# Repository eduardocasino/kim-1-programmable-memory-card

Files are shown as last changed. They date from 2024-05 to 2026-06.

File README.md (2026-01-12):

# KIM-1 Programmable Memory Board for the MTU Backplane

## **WARNINGS**

**THIS IS A WORK IN PROGRESS AND MAY CONTAIN ERRORS. USE AT YOUR OWN RISK!!!**

**Make sure to configure composite video output when connecting a composite monitor, and VGA output when using a VGA monitor. The video data and HSYNC pins are shared between both connectors, and if not properly configured, the signal MAY DAMAGE your monitor — especially older models.**

## About

This is a fully programmable RAM/ROM expansion board for the KIM-1. Two hardware versions are available which use exactly the same firmware and tools:

* One for MTU backplanes, like the one in the original K-1005 card file, my [expansion card](https://github.com/eduardocasino/kim-1-mtu-expansion-card) or my [buffered motherboard](https://github.com/eduardocasino/kim-1-mtu-motherboard).
* One for the [PAL-2](https://www.tindie.com/products/kim1/pal-2-a-mos-6502-powered-computer-kit/), a KIM-1 clone by Liu GN. **IMPORTANT: Read the hardware specific notes for the PAL-2**.

There is also [an adapter](https://github.com/eduardocasino/kim-1-programmable-memory-card/tree/main/hardware/pal-2-kim-adapter) for connecting the PAL-2 version directly to the KIM-1 expansion connector. This is the best option if you don't have/need/want an MTU backplane.

It uses a Raspberry Pi Pico W to emulate the 64K RAM/ROM memory map, and has some cool features:

* Can emulate RAM and/or ROM at any address of the KIM-1 memory map and with byte granularity so you can individually enable, disable, mark as RW or RO each and every byte of the 64K address space. It can also take over the KIM-1 system RAM and ROM, so it can be used as a diagnostic tool or to relive a KIM-1 with dead RAM.
* A default memory map and data are stored in the Pico flash memory and it is available at boot time.
* Runs a configuration web server with a RESTish API so you can configure and read or write all or any part of memory contents over Wifi and on the fly.
* The board is powered by the KIM-1, but it can also be dual powered by the KIM-1 and the USB port. This is useful, for example, if you are developing a boot ROM: you can power off the KIM, modify the boot program over wifi and turn it on again to test your changes.
* It emulates an [MTU K-1008 Visable Memory Card](https://github.com/eduardocasino/k-1008-visable-memory-card-replica). It can be mapped to the same addresses as the real one (and change that mapping while running) and gives configurable composite NTSC or PAL output through the RCA connector or VGA output through the DB-15 one. Simultaneous composite and VGA output is not possible.
* Emulates an [K-1013 floppy disk controller](http://retro.hansotten.nl/uploads/mtu/MTU%20K-1013%20manual.pdf) with up to four disks, reading and writing to disk images into the SD card (Still in beta)

A config utility, memcfg, is provided to setup the board and facilitate the communication with the REST API. This is an overview of its functionality. Please see the [README.md file](https://github.com/eduardocasino/kim-1-programmable-memory-card/tree/main/tools) for detailed usage instructions:

* Generate configuration files ready to be flashed into the Pico: WiFi parameters, video format and default memory map and contents.
* Get or modify the memory map.
* Read memory contents and generate output in different formats: hexdump, Intel hex, binary, prg and raw. The raw format is how the Pico stores the memory map. Each memory address contains a 16 bit integer. The least significant byte is the content and the most significant one is a bitmap that indicates if the memory is enabled or disabled and writeable or read-only.
* Write memory contents from file or command line. The file formats supported are Intel hex, binary, prg and raw. Also, binary and raw data can be specified as a string from the command line.
* Modify the base address for the K-1008 emulation
* Manages disk images

### [KIM-1 version](https://github.com/eduardocasino/kim-1-programmable-memory-card/tree/main/hardware/kim-1-mtu)
### [PAL-2 version](https://github.com/eduardocasino/kim-1-programmable-memory-card/tree/main/hardware/pal-2)
### [KIM-1 adapter for the PAL-2 version](https://github.com/eduardocasino/kim-1-programmable-memory-card/tree/main/hardware/pal-2-kim-adapter)
### [Firmware](https://github.com/eduardocasino/kim-1-programmable-memory-card/tree/main/firmware)
### [Tools (memcfg)](https://github.com/eduardocasino/kim-1-programmable-memory-card/tree/main/tools)

***NOTE***: This is a picture of a KIM-1 version prototype. The bodges are not needed in the current design.

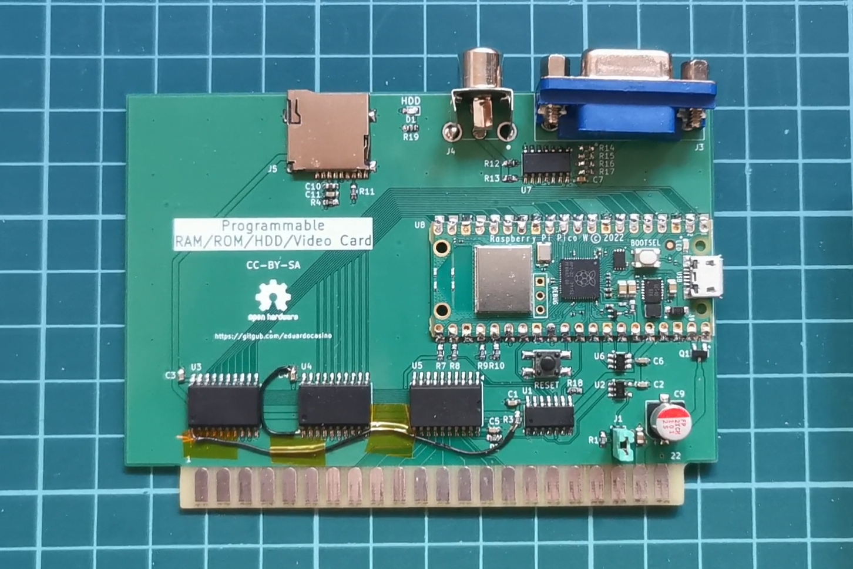
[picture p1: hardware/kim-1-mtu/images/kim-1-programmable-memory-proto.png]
kim-1 prototype


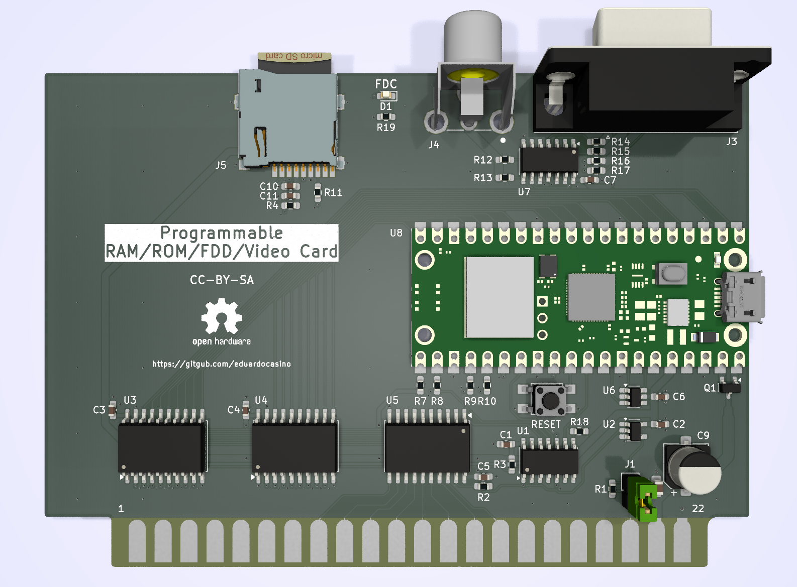
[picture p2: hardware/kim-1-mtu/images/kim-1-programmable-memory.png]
kim-1 components

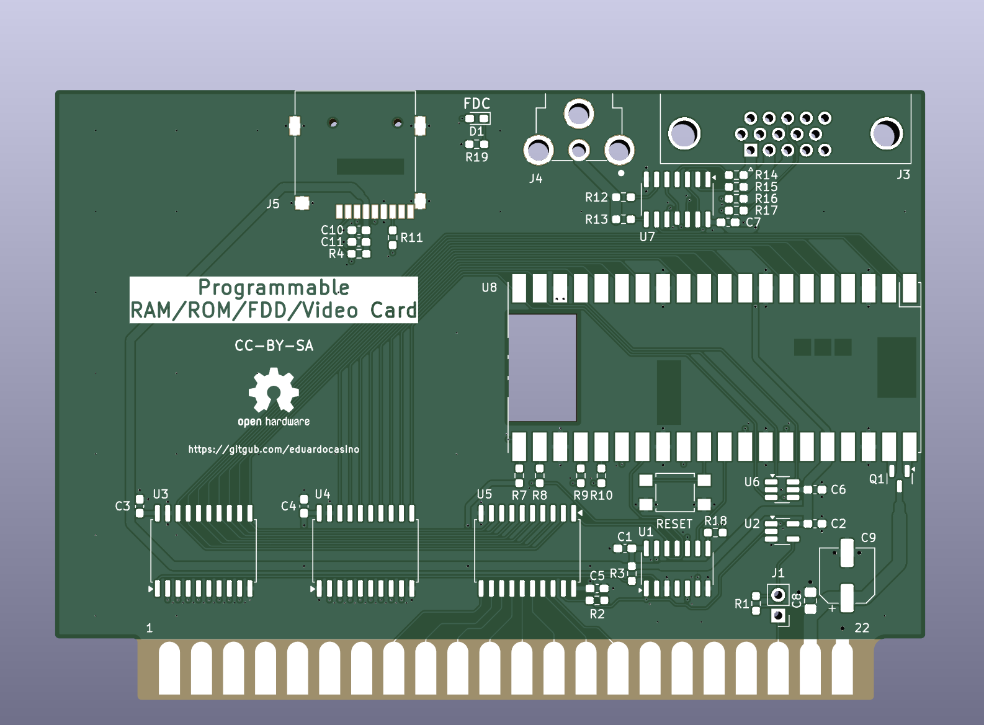
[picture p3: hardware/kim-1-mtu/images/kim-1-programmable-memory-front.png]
kim-1 front

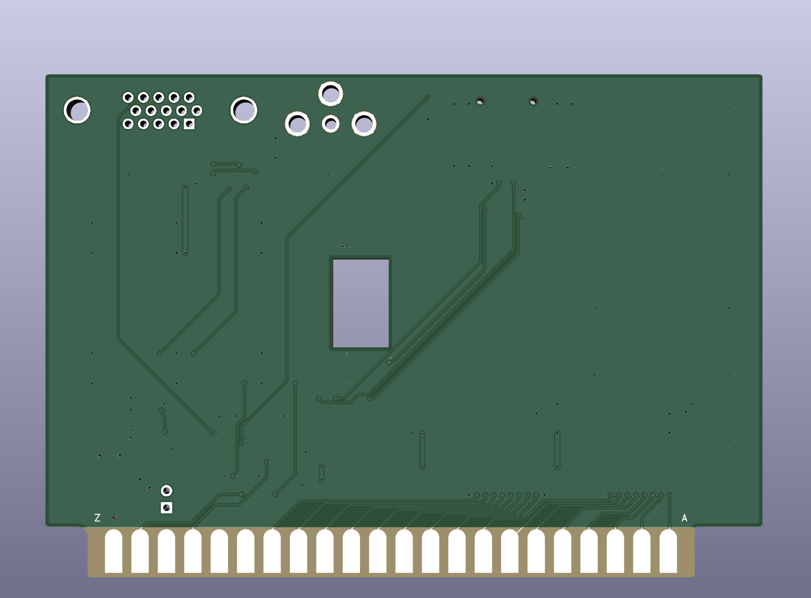
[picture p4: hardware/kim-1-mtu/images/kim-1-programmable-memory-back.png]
kim-1 back


pal-2 components
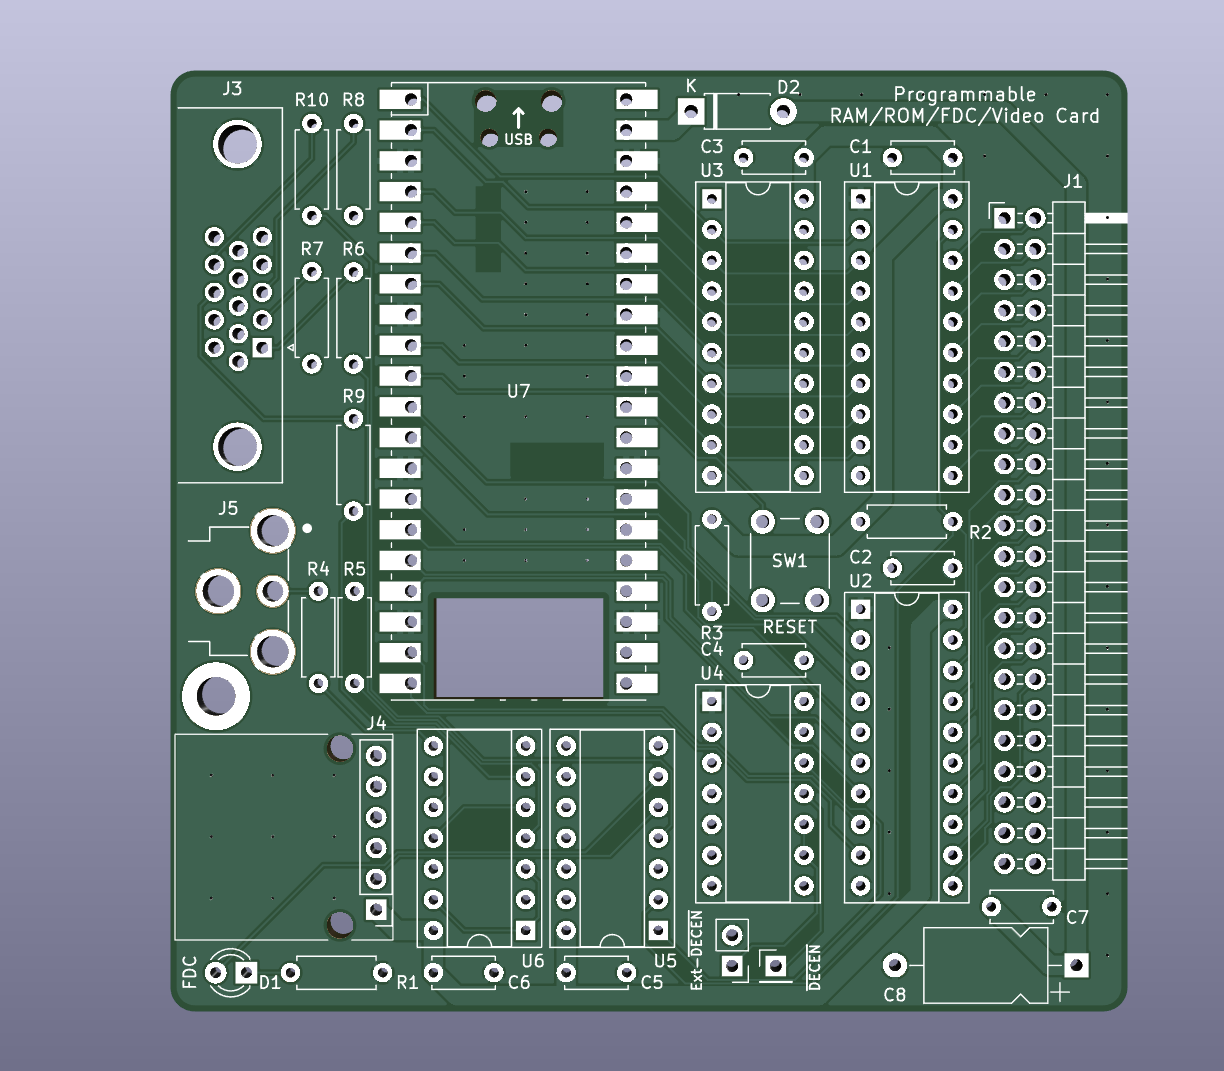
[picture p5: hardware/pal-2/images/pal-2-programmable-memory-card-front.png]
pal-2 front

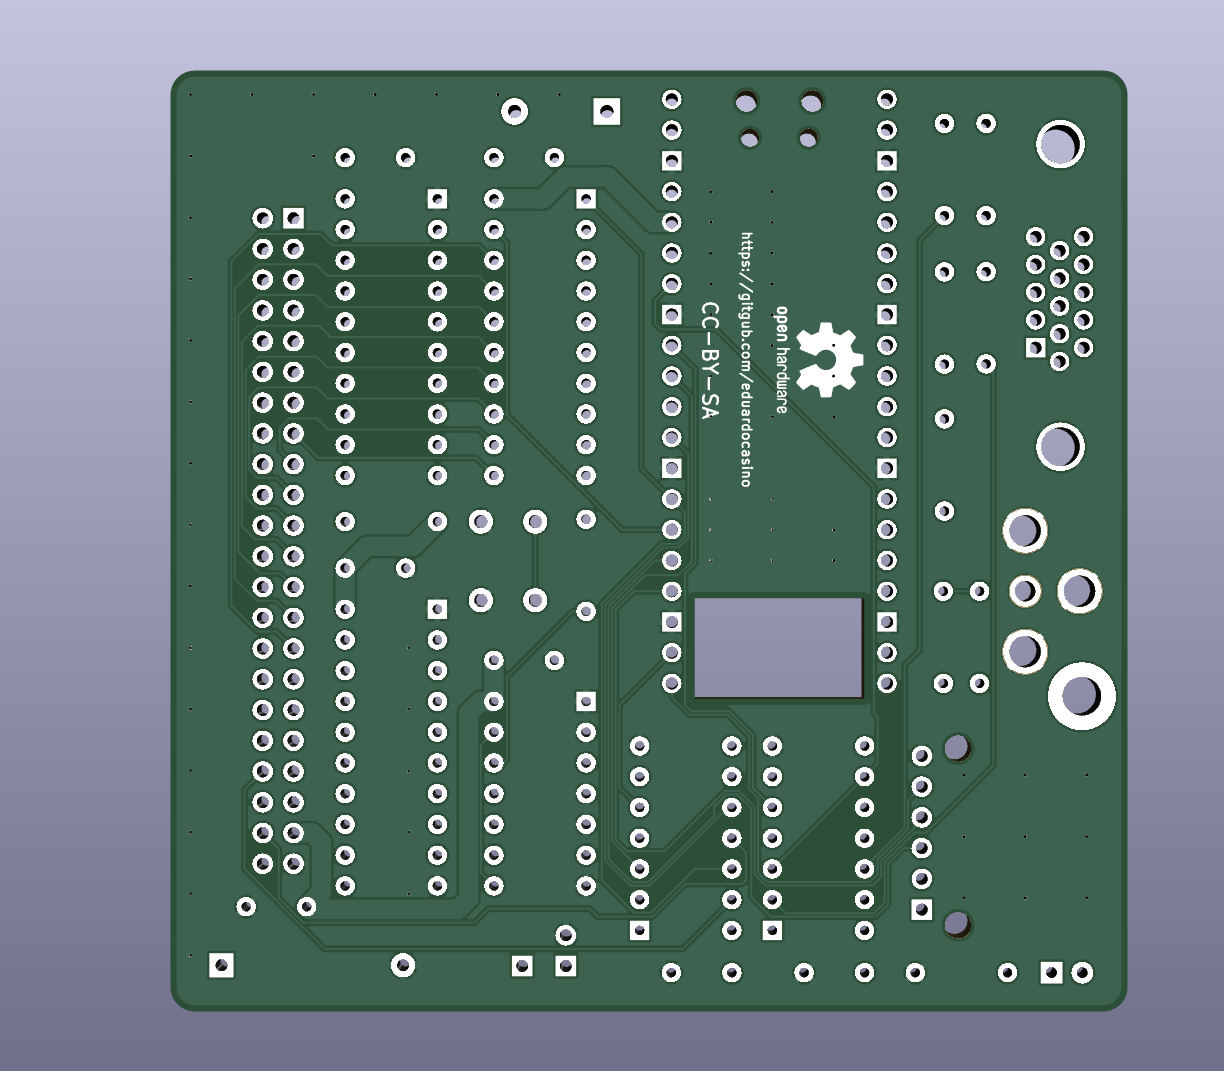
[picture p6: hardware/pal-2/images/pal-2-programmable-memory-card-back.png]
pal-2 back


## Licensing

This is a personal project that I am sharing in case it is of interest to any retrocomputing enthusiast and all the information in this repository is provided "as is", without warranty of any kind. I am not liable for any damages that may occur, whether it be to individuals, objects, KIM-1 computers, kittens or any other pets. **It should also be noted that everything in this repository is a work in progress, may have not been thoroughly tested and may contain errors, therefore anyone who chooses to use it does so at their own risk**.



This work is licensed under a [Creative Commons Attribution-ShareAlike 4.0 International License](http://creativecommons.org/licenses/by-sa/4.0/).

See the LICENSE.md file for details.

## Acknowledgements

* Richard Hulme for his [PicoROM implementation](https://github.com/rhulme/picoROM_pio).
* Jan Cumps on [how to reserve a flash memory block for persistent storage](https://community.element14.com/products/raspberry-pi/b/blog/posts/raspberry-pico-c-sdk-reserve-a-flash-memory-block-for-persistent-storage).
* Jeremy P Bentham for his [PicoWi library](http://iosoft.blog/picowi)
* Alan Reed for his [composite video output implementation](https://github.com/alanpreed/pico-composite-video).
* Hunter Adams for his [VGA implementation](https://github.com/vha3/Hunter-Adams-RP2040-Demos)
* Luciano Veronese for the BOM and component placement files for the KIM-1 version.

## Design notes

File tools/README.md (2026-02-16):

# memcfg - Command line utility for managing the KIM-1 Pico Memory Emulator card

Copyright (C) 2024 Eduardo Casino (https://github.com/eduardocasino) under the terms of the GNU GENERAL PUBLIC LICENSE, Version 3. See the LICENSE.md file for details.

## Build instructions

## Notice

I've only built it on a Debian Linux and on WSL with Ubuntu. I can't give support for other systems, sorry.

## Prerequisites

Any modern Linux distribution, tested on `Debian 12.6` and `Ubuntu 24.04`

Install the required packages (additional to the ones needed for building the firmware):
```console
$ sudo apt update
$ sudo apt install libyaml-dev libcurl4-openssl-dev
```

Note: `libcurl4-gnutls-dev` can be used instead. It does not matter as no TLS is used in the `memcfg` utility.

## Build

Just go to the `tools` directory and build it with `make`:
```console
$ cd tools
$ make
```

## Usage

### General

```text
memcfg [-h] | {read,write,file,mount,config,restore,setup} ...

    -h                  Shows the general usage help

    read                Read data from the memory emulator
    write               Write data to the memory emulator
    file                Manage files on the SD card
    mount               Manage mounts
    config              Configure address ranges of the memory emulator
    restore             Restore memory map to defaults
    setup               Generates an UF2 file for board configuration
```

### Read command

Dumps data from the Memory Emulation board

```text
memcfg read -h
memcfg read ip_addr -s OFFSET [-c COUNT] [-f {hexdump,bin,ihex,pap,prg,raw}] [-o FILE]

    ip_addr             The IP address of the Pico W in dot-decimal notation, e.g., 192.168.0.10

    -h                  Shows the read command help
    -s | --start OFFSET Offset in the KIM-1 address space from where read the data.
                        START must be an unsigned integer, either in decimal or hex (0x) notations,
                        in the range 0-65535 (0x0000-0xFFFF)
    -c | --count COUNT  Number of bytes to read. If not present, defaults to 256 (0x100)
                        START must be an unsigned integer, either in decimal or hex (0x) notations,
                        in the range 0-65536 (0x00000-0x10000)
    -f | --format       Format of the dumped data:
                        hexdump     ASCII hex dump in human readable format
                        bin         Binary data
                        ihex        Intel HEX format
                        pap         MOS papertape format
                        prg         Commodore PRG format (binary file with the two first bytes
                                    indicating the data offset)
                        raw         Mainly for debugging purposes. This is the data in the format
                                    it is stored in the board and may change in future revisions.
                                    Each memory location is 16 bit wide. Bits 0 to 7 are the data bits. Bit 8 flags if the location is enabled and Bit 9 flags if the location
                                    is writable.
    -o | --output FILE  FILE to save the data to. Mandatory for binary formats (bin, prg, raw), it
                        defaults to stdout for the rest
```

### Write command

Sends data to the Memory Emulation board

```text
memcfg write -h 
memcfg write ip_addr [-s OFFSET] [-f {bin,ihex,pap,prg,raw}] [-i FILE]|[-d STRING ] [-e]

    ip_addr             The IP address of the Pico W in dot-decimal notation, e.g., 192.168.0.10

    -h                  Shows the write command help
    -s | --start OFFSET Same as in the read command. Mandatory for bin and raw formats. Ignored
                        for prg and ihex.
    -f | --format       Mandatory. Format of the dumped data:
                        bin         Binary data

                        ihex        Intel HEX format
                        pap         MOS papertape format
                        prg         Commodore PRG format (binary file with the two first bytes
                                    indicating the data offset)
                        raw         Mainly for debugging purposes. This is the data in the format
                                    it is stored in the board and may change in future revisions.
                                    Each memory location is 16 bit wide. Bit 11 flags if the location
                                    is writable, Bit 0 flags if the location is enabled and Bits
                                    11, 10, 6, 5, 4, 3, 2 and 1 are the data bits in reversed order.
    -i | --input FILE   FILE to read the data from. Mandatory for ihex, pap and prg formats.
    -d | --data STRING  String to transfer. Can include hex and oct escaped binary chars. Either a
                        string or an input file must be specified for bin and raw formats. Not valid
                        for ihex, pap or prg.
    -e | --enable       Enables the written address block
```

### File command

Manages files on the SD card

```text
memcfg file -h

    -h                      Shows the file command help

memcfg file ip_addr

    ip_addr                 The IP address of the Pico W in dot-decimal notation, e.g., 192.168.0.10

    Without extra arguments, lists files on the SD card to stdout

memcfg file ip_addr [-r|-s] FILE [-l LFILE] [-f]

    -r | --receive FILE     Get FILE from SD card
    -s | --send    FILE     Send FILE to SD card
    -l | --local   LFILE    Local filename (defaults to FILE)
    -f | --force            Force file overwrite (use with care)

memcfg file ip_addr -d FILE

    -d | --delete  FILE     Remove FILE from SD card

memcfg file ip_addr [-c|-m] FILE NFILE [-f]

    -c | --copy    FILE NFILE  Copy FILE to NFILE on the SD card
    -m | --move    FILE NFILE  Rename FILE to NFILE on the SD card
    -f | --force   (Only for -c|--copy) Force file overwrite
```

### Mount command

Manages mounts

```text
memcfg mount -h

    -h                      Shows the mount command help

memcfg mount ip_addr [-s]

    ip_addr                 The IP address of the Pico W in dot-decimal notation, e.g., 192.168.0.10

    -s | --save             Save current mounts as default

    Without extra arguments, lists current mounts

memcfg mount ip_addr -d DRIVE {-f FILE [-r] | -u}

    -d | --drive   DRIVE    Drive to mount/unmount (from 0 to 3)
    -f | --file    FILE     Image file to mount
    -u | --umount           Unmount drive
    -r | --ro               Mount drive as read-only
```

### Config command

Configures the emulated memory map

```text
memcfg config -h

    -h                      Shows the config command help

memcfg config ip_addr [-o FILE]

    ip_addr             The IP address of the Pico W in dot-decimal notation, e.g., 192.168.0.10

    Without extra arguments, prints the memory map configuration to stdout

    -o | --output FILE      File to save the config to. If not specified, defaults to stdout

memcfg config ip_addr [-d RANGE [-d RANGE ...]] [-e RANGE [-e RANGE ...]]
                             [-r RANGE [-r RANGE ...]] [-w RANGE [-w RANGE ...]]
                             [-v OFFSET] [-i FILE] [-o FILE]

    RANGE                   The address range(s) to apply each option. The format is
                            0xHHHH-0xHHHH, where HHHH are hexadecimal numbers
    -d | --disable RANGE    Sets the specified RANGE as disabled. The data bus will remain
                            in high impedance state when it is addressed.
    -e | --enable RANGE     Sets the specified RANGE as enabled.
    -r | --readonly RANGE   Configures the RANGE as ROM
    -w | --writable RANGE   Configures the RANGE as RAM
    -v | --video OFFSET     Video memory start address
    -i | --input FILE       Uses yaml FILE for configuration. See the config file format below.
    -o | --output FILE      File to save the config to 

Options with RANGEs may be specified multiple times. The options are interpreted in the following order:
FILE, disable, enable, readonly and writable. So, for example:

    memcfg ip_addr config -r 0xe000-0xffff -e 0x0400-0x13ff -w 0x0400-0x13ff -e 0xe000-0xffff -d 0x0000-0xfffff

will first mark the whole memory map as disabled, will then enable the ranges 0x400-0x13ff and
0xe000-0xffff, then mark 0xe000-0xffff as ROM and, finally, set 0x400-0x13ff as RAM.
```

### Restore command

Restore memory map to defaults.

```text
memcfg restore -h | ip_addr

    ip_addr                 The IP address of the Pico W in dot-decimal notation, e.g., 192.168.0.10
    -h                      Shows the config command help
```

### Setup command

Generates UF2 configuration file.

```text
memcfg setup -h
memcfg setup [-s FILE] [-m FILE] -o FILE

    -h                      Shows the config command help
    -s | --setup FILE       Setup configuration file. See format below
    -m | --memory FILE      Default memory map file. Same format as the config filr
    -o | --output FILE      Generated UF2 file

At least one of '-m' or '-s' files must be specified.
```

### Config file format

The config file is just a YAML document with three keys, all mandatory:

```yaml
---
wifi:
 country: <countrycode>              # Standard 2 or 3 character country code, like 'ES' or 'FR' 
 ssid: mywifisid                     # Your wifi SID
 password: mysupersecretwifipassword # Your wifi password
video:                               # K-1008 Video Card emulation
 system: <video_system>              # 'ntsc', 'pal', 'vga400' or 'vga480'
 address: <integer>                  # Offset address of the video memory
fdc:                                 # K-1013 FDC emulation
 enabled: <bool>                     # Wether if the FDC emulation is enabled or not
 usrram: <integer>                   # Address of the User DMA RAM block
 sysram: <integer>                   # Address of the System DMA RAM block
 optswitch: <bool>                   # Optional: Enable/disable the card "options" switch.
```

There are two VGA modes available: 640x400@70Hz and 640x480@60HZ (with horizontal bars) Choose the one that suits your monitor better.

The valid adresses for the K-1008 and K-1013 emulation are: `0x2000, 0x4000, 0x6000, 0x8000, 0xA000, 0xC000 and 0xE000`

#### NOTE

In previous versions, additional `disk0`, `disk1`, `disk2` and `disk3` keys where available in the `fdc` section for mounting disk images at boot. Now, the firmware looks for the `mount.cfg` file at the SD card root, which has the following format:

```text
# This is a comment and is ignored
# Lines have the following format:
#   <drive>:<filename>[:r]
# where:
#   <drive> is a number between 0 and 3
#   <filename> is the name of the IMD image
#   r (or R) makes the drive read-only
#
0:image0.imd
3:image1.imd:r
```

### Memory config file format

**memcfg** uses a simple YAML file for configuration. Each section is a YAML document and they are processed in the same order as they appear in the document. Three hyphens mark the beginning of a new document. Text after a '#' are comments and not processed. Valid *key:value* pairs are:

```yaml
start: <integer>        # Mandatory. Offset address for this section. 
end: <integer>          # Mandatory if no'file' nor 'data' are present. End
                        #           address of the section.
enabled: true|false     # Optional. Marks the section as enabled or disabled.
type: ram | rom         # Optional. Marks the section as RAM or ROM.
file: 'filename'        # Optional. Initializes section with the file contents.
                        #           Must be binary.
                        #           if the file is bigger than the sections, it
                        #           is truncated and a warning is issued.
fill: <byte>            # Optional. Fills the section with <byte>. If file is 
                        #           also specified and its smaller than the
                        #           section, fills the remaining space.
data: 'string'          # Optional. Fills the section with the string contents. Hex
                        #           and Oct escape codes (like '\xFF' or '\177') are
                        #           supported. IMPORTANT NOTE: Hex escape codes are
                        #           only supported with single quote srting style!
```

Example:

```yaml
---
# Disable the whole address map by default
start: 0x0000
end: 0xffff
enabled: false
type: rom
fill: 0x00
---
# System RAM + ram hole
start: 0x0000
end: 0x13ff
enabled: true
type: ram
---
# RRIOT RAM
start: 0x1780
end: 0x17f9
enabled: true
type: ram
---
# Interrupt vectors
start: 0x17fa
end: 0x17ff
enabled: true
type: ram
data: "\x00\x1c\x00\x00\x00\x1c"
---
# System ROM
start: 0x1800
end: 0x1fff
enabled: true
type: rom
file: "kim.bin"
---
start: 0x2000
end: 0xdfff
enabled: true
type: ram
---
start: 0xe000
end: 0xffff
enabled: true
type: rom
file: "customrom.bin"
fill: 0xff
---
# Put KIM vectors at the end
# NOTE: The memory card does not manage the K7 line,
#       so the interrupt vectors must ALWAYS be present
#       at 0xFFFA-0xFFFF
type: rom
start: 0xFFFA
data: '\x1c\x1c\x22\x1c\x1f\x1c'
enabled: true
```

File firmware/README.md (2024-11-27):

# Build instructions

## Notice

I've only built it on a Debian Linux and on WSL with Ubuntu. I can't give support for other systems, sorry.

## Prerequisites

Any modern Linux distribution, tested on `Debian 12.6` and `Ubuntu 24.04`

Install the required packages:
```console
$ sudo apt update
$ sudo apt install git cmake gcc-arm-none-eabi libnewlib-arm-none-eabi build-essential libyaml-dev libcurl4-openssl-dev
```

Note: `libcurl4-gnutls-dev` can be used instead. It does not matter as no TLS is used in the `memcfg` utility.

## Build

Clone this repository and update the sdk submodule:
```console
$ git clone git@github.com:eduardocasino/kim-1-programmable-memory-card.git
$ cd kim-1-programmable-memory-card
$ git submodule update --init --recursive
```

Go to the `firmware` repository, create the `build` repository and change to it:
```console
$ cd firmware
$ mkdir build
$ cd build
```

Generate the `CMake` files.
```console
PICO_SDK_PATH=../pico-sdk cmake ..
```

Build it with `make`:
```console
$ make
```

If everything went well, you should have a `mememul.uf2` file in the build directory.

Now, go to the tools directory and build the `memcfg`utility:
```console
$ cd ../../tools
$ make
```

Connect the board to your PC with an USB cable. Press the bootloader mode button on the Pico and, while holding it, push the reset button. Release them and your Pico will be in bootloader mode. An `RPI-RP2` removable unit should be now mounted. Transfer the `mememul.uf2` file to its root and wait until the Pico reboots. You should see the green led blinking.

## First configuration

Create the `setup.yaml` and `memmap.yaml` files. You can use the ones in the [README.md](https://github.com/eduardocasino/kim-1-programmable-memory-card/blob/main/tools/README.md#config-file-format) as a template.

Execute the `setup`command:
```console
$ memcfg setup -s setup.yaml -m memmap.yaml -o setup.uf2
```

Put the Pico in bootloader mode again and transfer the `setup.uf2` file. When the Pico reboots, the green led should blink rapidly and turn continuosly on in a few seconds. That means that it has succesfully joined your network and it has been assigned an IP address. Use a terminal program such as `Tera Term` to connect to the pico and write down the assigned address (you will have to press the reset button after you connect through the terminal to force a reboot)

If the led goes on blinking, check the `setup.yaml` file and ensure that your network info is correct.

At this point your card should be ready and you can manage it with the `memcfg` tool. Try this:
```console
$ memcfg config <ip_address>
```

You should see an output similar to this:
```text
---
start: 0x0000
end: 0x13ff
enabled: true
type: ram
---
start: 0x1400
end: 0x177f
enabled: false
type: rom
---
start: 0x1780
end: 0x17ff
enabled: true
type: ram
---
start: 0x1800
end: 0x1fff
enabled: true
type: rom
---
start: 0x2000
end: 0xdfff
enabled: true
type: ram
---
start: 0xe000
end: 0xffff
enabled: true
type: rom
```

You can now disconnect the cable and use the card with your KIM-1!

***NOTE***: It is safe to mantain the card connected to the PC while using it with the KIM. Just do not connect or disconnect the cable while the KIM-1 is turned on, to avoid possible electrostatic discharges. It can be useful if you are trying different default memory maps or modifying the firmware.

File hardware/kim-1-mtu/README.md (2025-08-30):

# Notes for the KIM-1 MTU version

## BOM and component placement list

Thanks to Luciano Veronese, we now have a [BOM](https://github.com/eduardocasino/kim-1-programmable-memory-card/tree/main/hardware/kim-1-mtu/docs/bom.csv) and a [component placement list](https://github.com/eduardocasino/kim-1-programmable-memory-card/tree/main/hardware/kim-1-mtu/docs/positions.csv) for use with JLCPCB. They are under the [docs folder](https://github.com/eduardocasino/kim-1-programmable-memory-card/tree/main/hardware/kim-1-mtu/docs/).

Only the coaxial connector and the PicoW are missing, but they are very easy to solder.

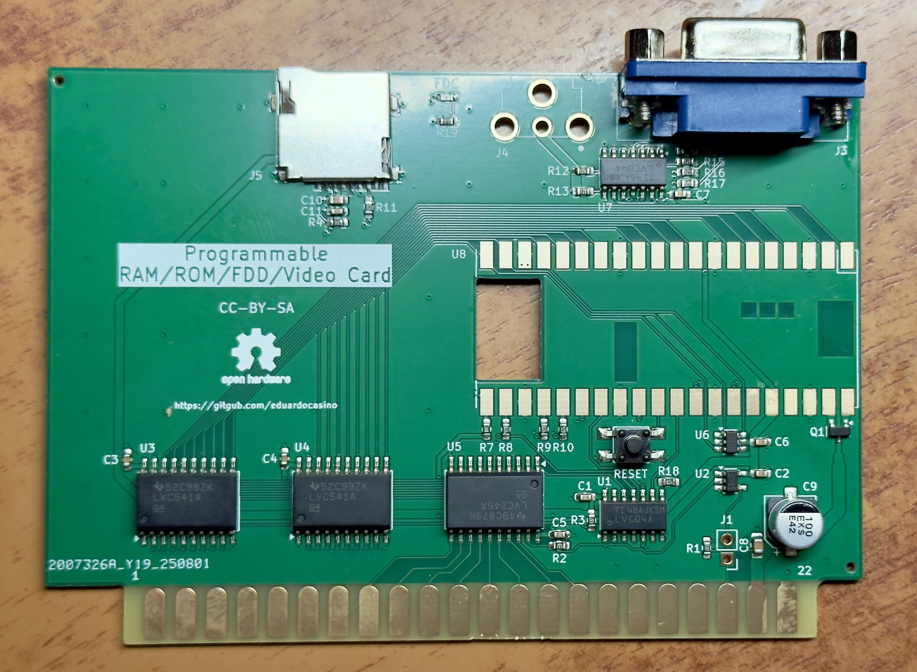
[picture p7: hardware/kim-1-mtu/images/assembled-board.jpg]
assembled board


Picture by Luciano Veronese

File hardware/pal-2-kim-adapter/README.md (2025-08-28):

# PAL-2 version to KIM-1 adapter

## DECEN signal

As well as for the PAL, the DECEN pin must be connected to pin K in the Application connector. You can do this using a clip probe.

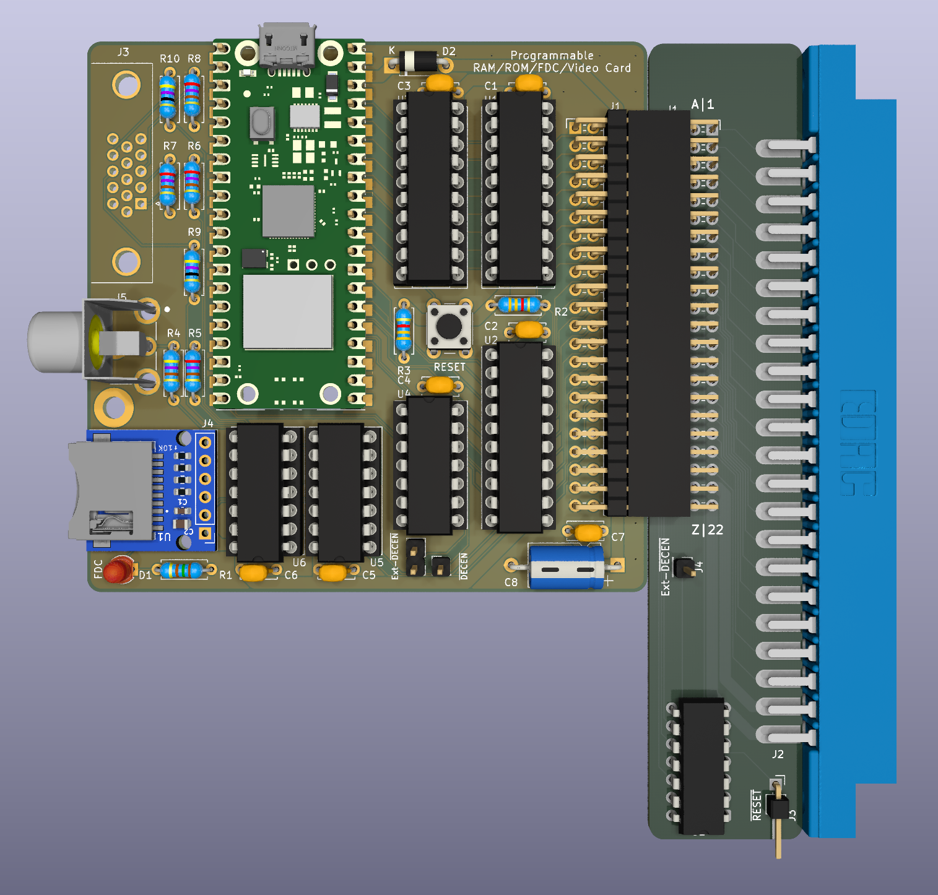
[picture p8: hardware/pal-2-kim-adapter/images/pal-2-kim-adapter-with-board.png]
adapter with board

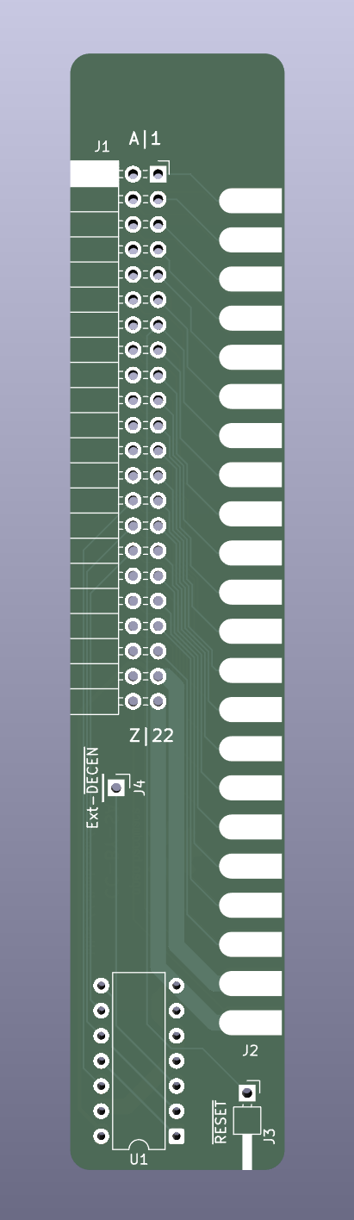
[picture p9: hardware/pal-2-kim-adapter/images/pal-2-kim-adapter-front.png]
adapter front

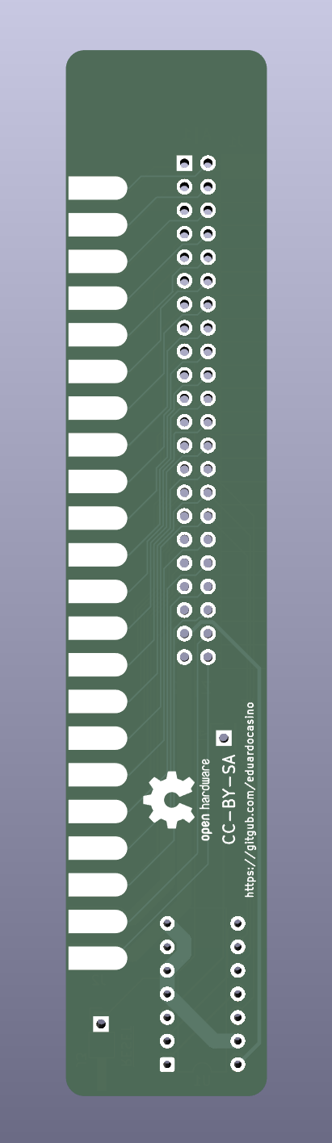
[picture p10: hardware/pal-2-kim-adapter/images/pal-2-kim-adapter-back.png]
adapter back


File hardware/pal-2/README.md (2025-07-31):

# Notes for the PAL-2 version

## DECEN signal

The DECEN pin must be connected to pin K in the Application connector. You can do this using a clip probe as shown in the picture below:

DECEN picture

## PAL-2 mod

### **WARNING**

**THIS MOD MAY DAMAGE YOUR PAL-2 IF PERFORMED INCORRECTLY. DO IT AT YOUR OWN RISK!!!**

The PAL-2 behaves differently from the KIM-1 when the #DECEN signal goes high.

On the KIM-1, this signal disables all internal address decoding, allowing an expansion card to take over. However, on the PAL-2, the signal is wire-ORed with the 8K0 enable output of the first decoder, so it effectively has no impact.

To enable expansion card functionality, a simple modification must be performed on the PAL-2:

* Cut the trace that connects pin K of the Application connector to pin 12 of U6, and the trace connecting pin 12 of U8 to ground.
* Solder a wire from pin K of the Application connector to pin 12 of U8.
* Solder a 3.9kΩ resistor from pin 12 of U8 to any ground point on the board.

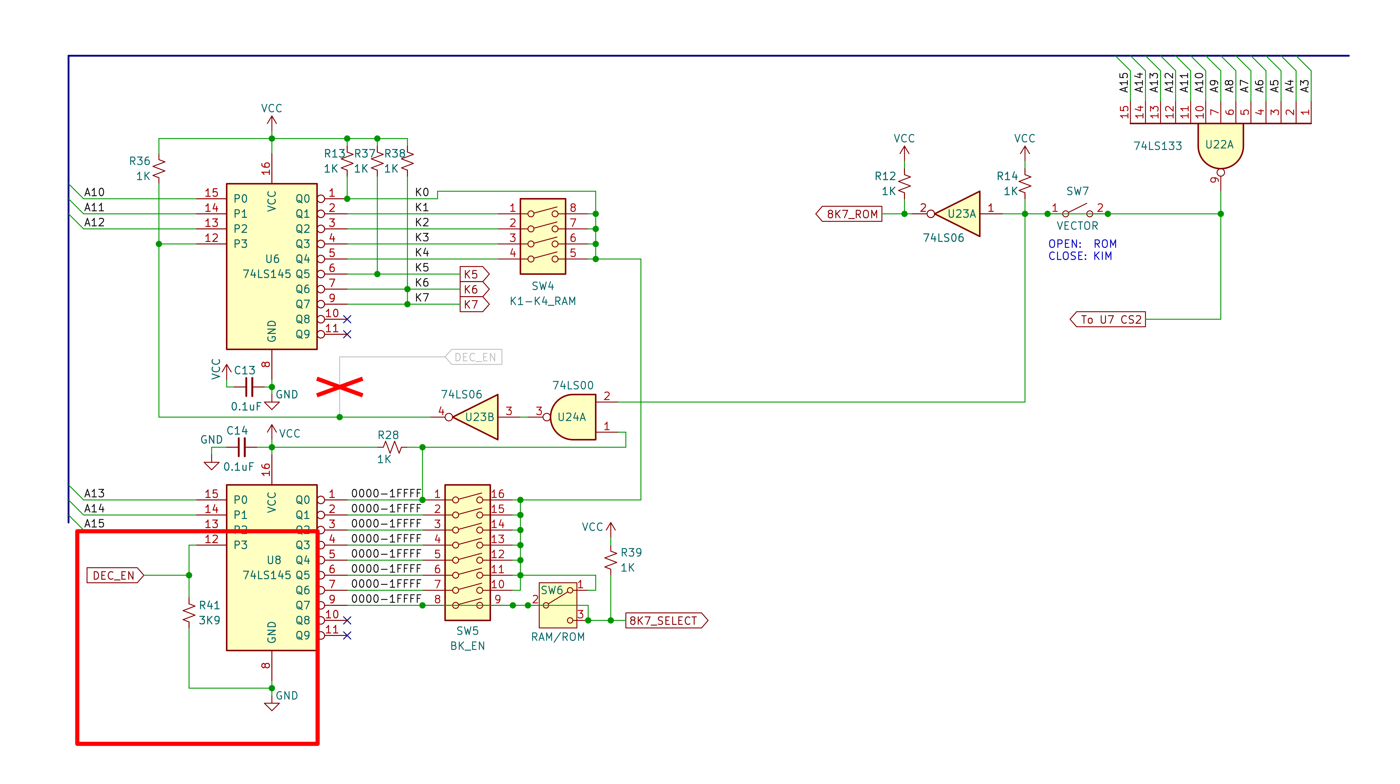
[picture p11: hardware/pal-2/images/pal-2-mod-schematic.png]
mod schematic

mod picture

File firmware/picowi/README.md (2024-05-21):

# PicoWi: standalone WiFi driver for the CYW43439 on the Pi Pico W
See https://iosoft.blog/picowi for details

For the Pi Pico RP2040 webcam project, see part 10: http://www.iosoft.blog/picowi_part10

Copyright (c) Jeremy P Bentham 2023

Changes 18/05/2024 by Eduardo Casino https://github.com/eduardocasino :

* Remove all PIO and DMA code
* Add proper support for WiFi country codes
* Add support for POST/PUT/PATCH HTTP methods and large (multi-packet) HTTP requests

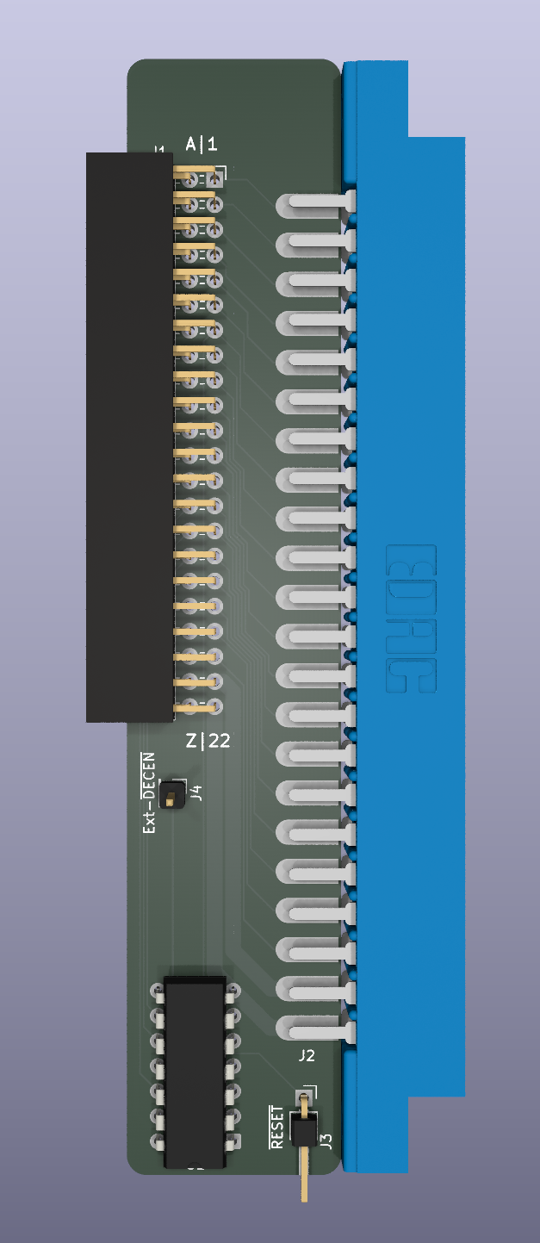
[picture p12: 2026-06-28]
hardware/pal-2-kim-adapter/images/pal-2-kim-adapter.png

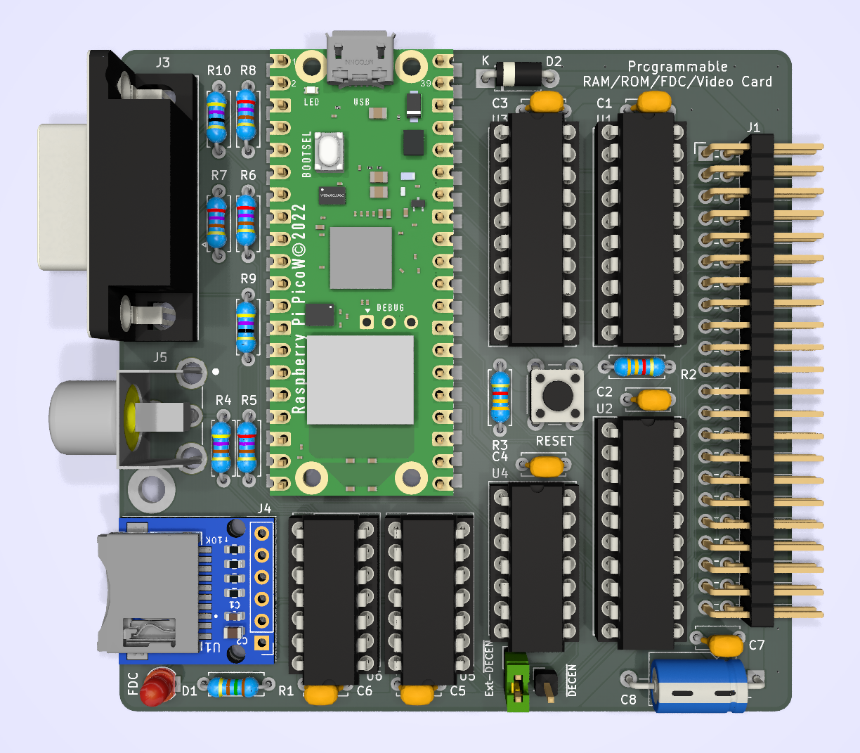
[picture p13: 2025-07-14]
hardware/pal-2/images/pal-2-programmable-memory-card.png

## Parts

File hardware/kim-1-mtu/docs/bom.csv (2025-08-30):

Designator | Footprint | Quantity | Value | LCSC Part #
C1, C11, C2, C3, C4, C5, C6, C7 | 0603 | 8 | 100nF | C14663
C10 | 0603 | 1 | 10uF | C96446
C8 | 0805 | 1 | 100nF | C28233
C9 | CP_Elec_6.3x5.9 | 1 | 100uF | C178540
D1 | 0603 | 1 | FDC | C2286
J3 | DSUB-15-HD_Female_Horizontal_P2.29x1.98mm_EdgePinOffset3.03mm_Housed_MountingHolesOffset4.94mm | 1 | VGA | C711364
J5 | SD_Card_Holder_SMD_WQ21801-B2180-7F | 1 | Micro_SD_Card_Det1 | C266620
Q1 | SOT-23 | 1 | DMG2305UX | C150470
R1, R2, R3 | 0603 | 3 | 3K3 | C22978
R10, R11, R17, R18, R8, R9 | 0603 | 6 | 47R | C23182
R12 | 0603 | 1 | 470R | C23179
R13, R14, R15, R16 | 0603 | 4 | 270R | C22966
R19 | 0603 | 1 | 150R | C22775
R4, R7 | 0603 | 2 | 10K | C25804
SW1 | SW_SPST_TL3305A | 1 | RESET | C455245
U1, U7 | SOIC-14_3.9x8.7mm_P1.27mm | 2 | LVC04 | C485074
U2 | SOT-23-5_HandSoldering | 1 | 74LVC1G38 | C2867613
U3, U4 | SOIC-20W_7.5x12.8mm_P1.27mm | 2 | 74LVC541 | C2652110
U5 | SOIC-20W_7.5x12.8mm_P1.27mm | 1 | 74LVC245 | C571201
U6 | SOT-23-6_Handsoldering | 1 | 74LVC1G27 | C128410

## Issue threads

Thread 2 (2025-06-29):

Question related to KIM-1 RAM-ROM memory card design

renejeanmercier, 2025-06-29:
Grettings Mr Casino,

This is a very nice design your RAM-ROM memory card design. Thank you for sharing.

Question: Why U3 (74LS145) pin 6 (Q5) is not connected with Q6 and Q7?  According to KIM-1 documentation (Memory Map FIGURE 3.12), K5 --Address 1400 to 17FF-- has the RIOT chips access between 1700 to 17FF (top quarter of this 1k memory space.

Thank you for helping me to understand.

Regards,

Rene_J

eduardocasino, 2025-06-29:
Hi Rene,

Thank you for your interest in my little project.

The design of the board tries to be as flexible as possible, while keeping things as simple as possible. The lower 8K of the memory map are then divided into 1K blocks by U3 and its outputs are grouped into three blocks: "System RAM" (0x0000-0x03FF), "Memory hole" (0x0400-0x13FF) and "System ROM" (0x1800-0x19FF). This allows to use a KIM-1 with defective RAM, replace the system ROM with a custom one and/or fill the 0x0400-0x13FF hole with RAM.

The 0x1400-1x17FF space is a bit trickier. As you well said, 0x1400-0x16FF is free and could be used for RAM, but 0x1700-0x17FF is the memory space of the RRIOT chips. So, that last 256 byte space can't be replaced with memory, or the KIM would stop working. It would be necessary to add another decoder to do it properly. So, I made a design decission to keep it simple and reserve the 0x1400-0x16FF addresses for IO space, so another expansion card could add VIAs or UARTs.

Connecting Q5 with Q6 and Q7 is not an option, as that would replace the RRIOT space with ROM.

I hope this helps.

Regards,
Eduardo

renejeanmercier, 2025-06-29:
Hi Eduardo,

Thank you very much for the time you took to reply this lengthy response. It is much appreciated.

This is clear now.

Another question if I may. What is the purpose of bringing low K7 (this output of the decoder on the KIM-1) ?

And finally, which program (in general) and monitor program (in particular) have you loaded in EEPROM ?

Thank you and ...

Best regards from Québec, Canada!

René-Jean

renejeanmercier, 2025-07-01:
Hi Eduardo,

I don't know if you live in Europe, but if so you better stay in an air
conditioned place!

Thank you for your time and your very useful explanations.

I am an old man... I designed in the 80's in assembler with CP/M on a Z-80
machine from Heathkit ;-). And later on with CP/M-86! It was an application
to process a schedule to drive a computer which was starting and stopping
Sony video recorders in playback mode to go "on-air" in one of our
television stations! ...Long time ago. I own an ALTAIR and an IMSAI
computers. Most of my designs in assembler and C were for 8080 and Z-80
processors. I own a KIM-1 because I gave courses on assembly language
programming to the technicians in my company at the end of the 70's and
KIM-1 was cheap to provide to the technicians. But I never used my
KIM-1until I realised that the second edition of the MOS Technology 3 books
of my documentation (I have the original edition of August 1976) will be 50
years old next year. I told myself that it was time for old technology to
meet with modern technology! So I designed an IO module using a D1-mini, so
that I can access the KIM-1 remotely in a telnet application on my home
network. That works quite nicely.

I see that you are working on a brilliant application using an RP2040. Once
I am done with the memory module, if time permits, I might build your
"second" generation of system. It would be great to run CP/M attached to a
KIM-1...

Thank you very much for sharing your knowledge in your 2 emails. This is
clever. I did not see anywhere else the use of the K7 pin to control KIM-1.
So that means that pin20 and pin 19 have to be routed to the appropriate
location on the KIM-1 module. I will redo the layout using smd components
because my KIM-1 is in a case and I have only  some 100mm from the
connector to the edge of the casing.

I will keep you informed ...and if I may ...get back to you in case I run
into trouble :-).

My best regards to you Eduardo !

René-Jean

Le lun. 30 juin 2025, à 10 h 08, Eduardo Casino ***@***.***>
a écrit :

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

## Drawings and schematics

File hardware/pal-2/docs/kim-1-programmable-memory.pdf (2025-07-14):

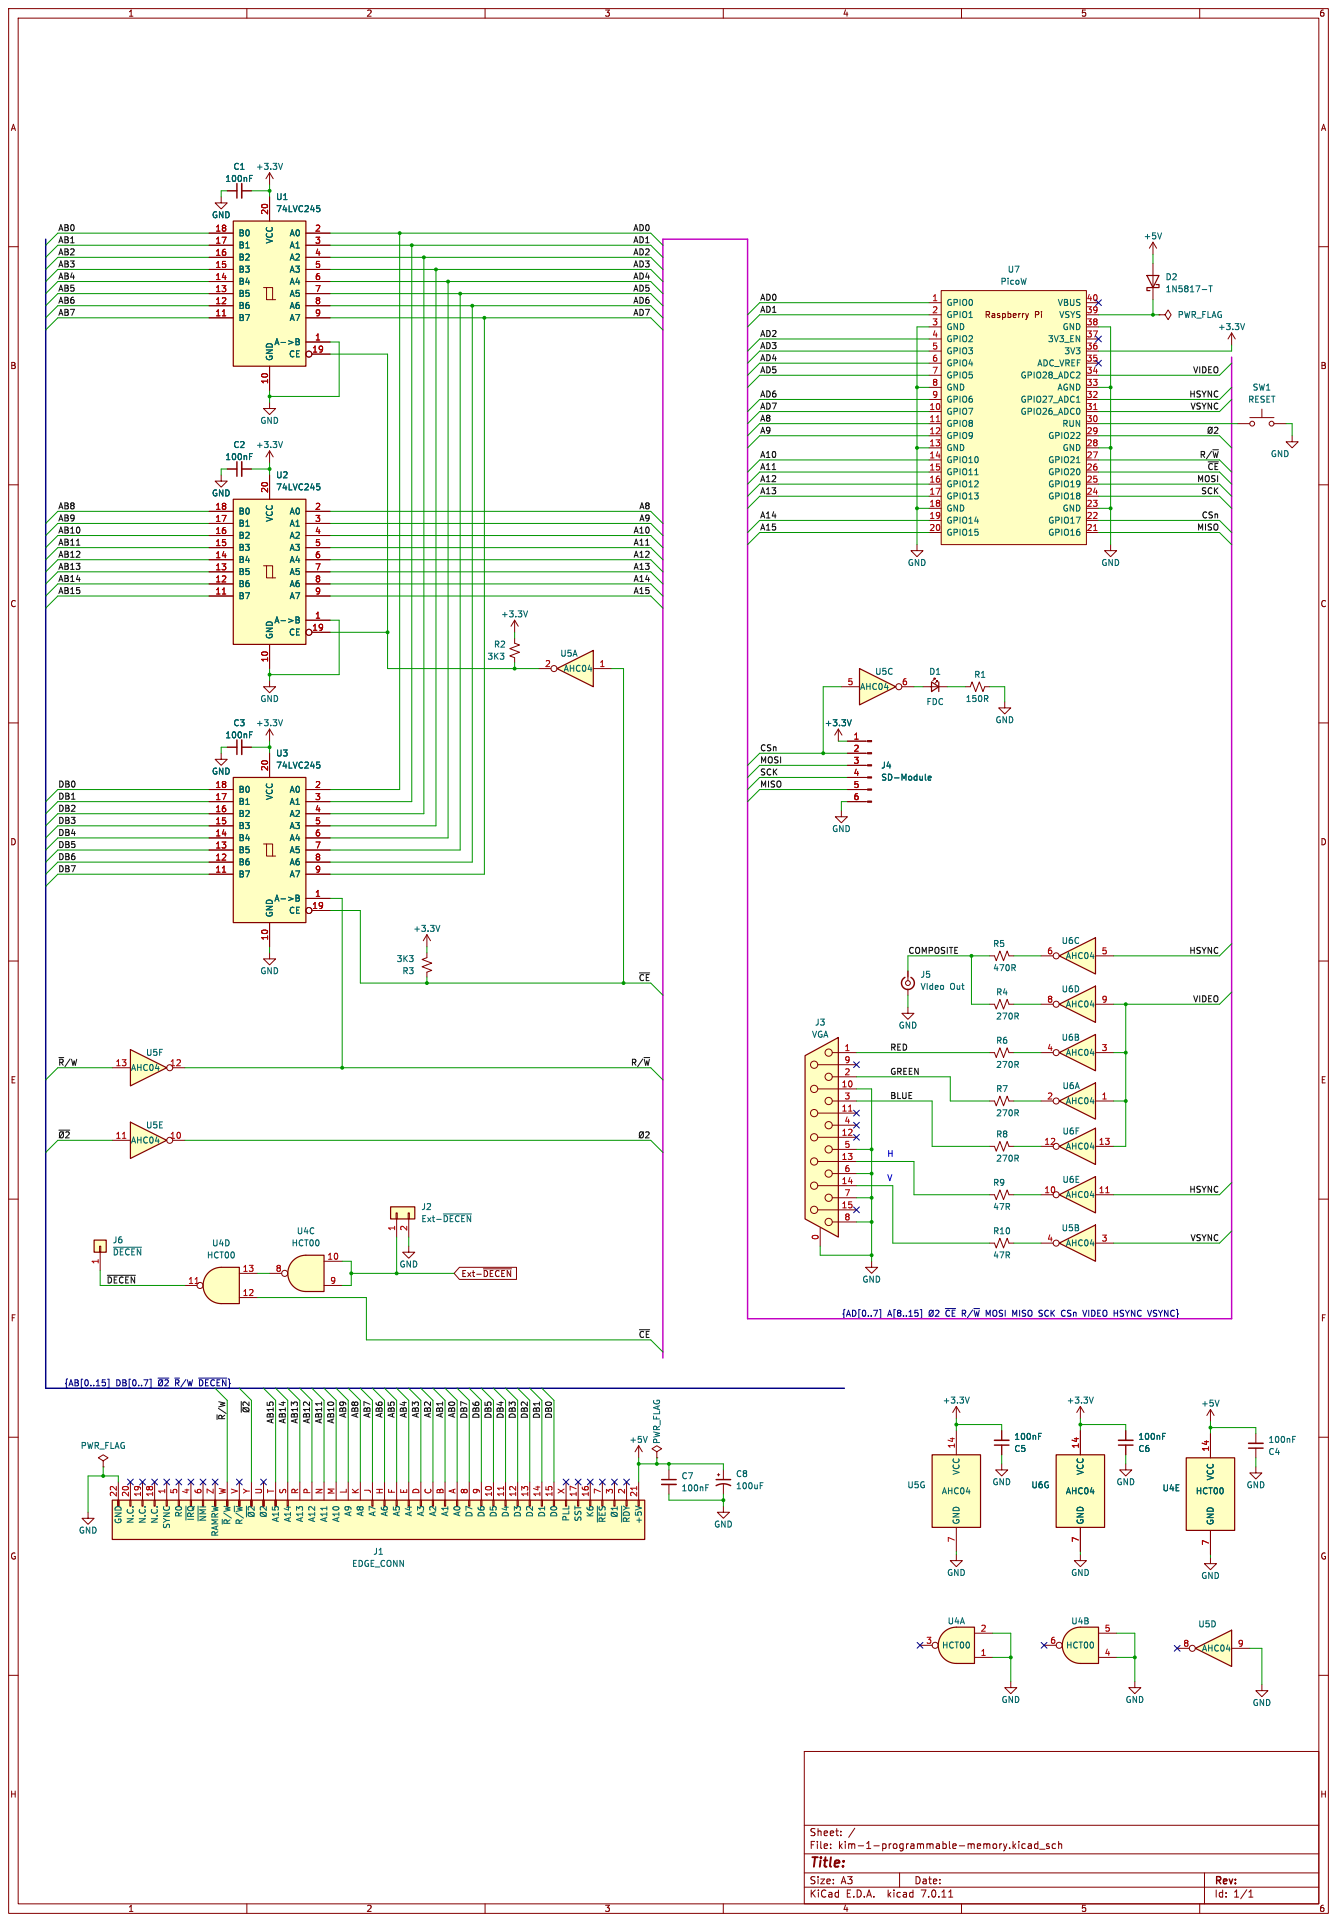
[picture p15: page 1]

1 D5 10 D4 11 D3 12 D2 13 D1 14 D0 15 K6 16 SST 17 N.C. 18 N.C. 19 ~{RDY}2 N.C. 20 +5V 21 GND 22 þÿØ1

Id: 1/1 Title: File: kim-1-programmable-memory.kicad_sch Sheet: /

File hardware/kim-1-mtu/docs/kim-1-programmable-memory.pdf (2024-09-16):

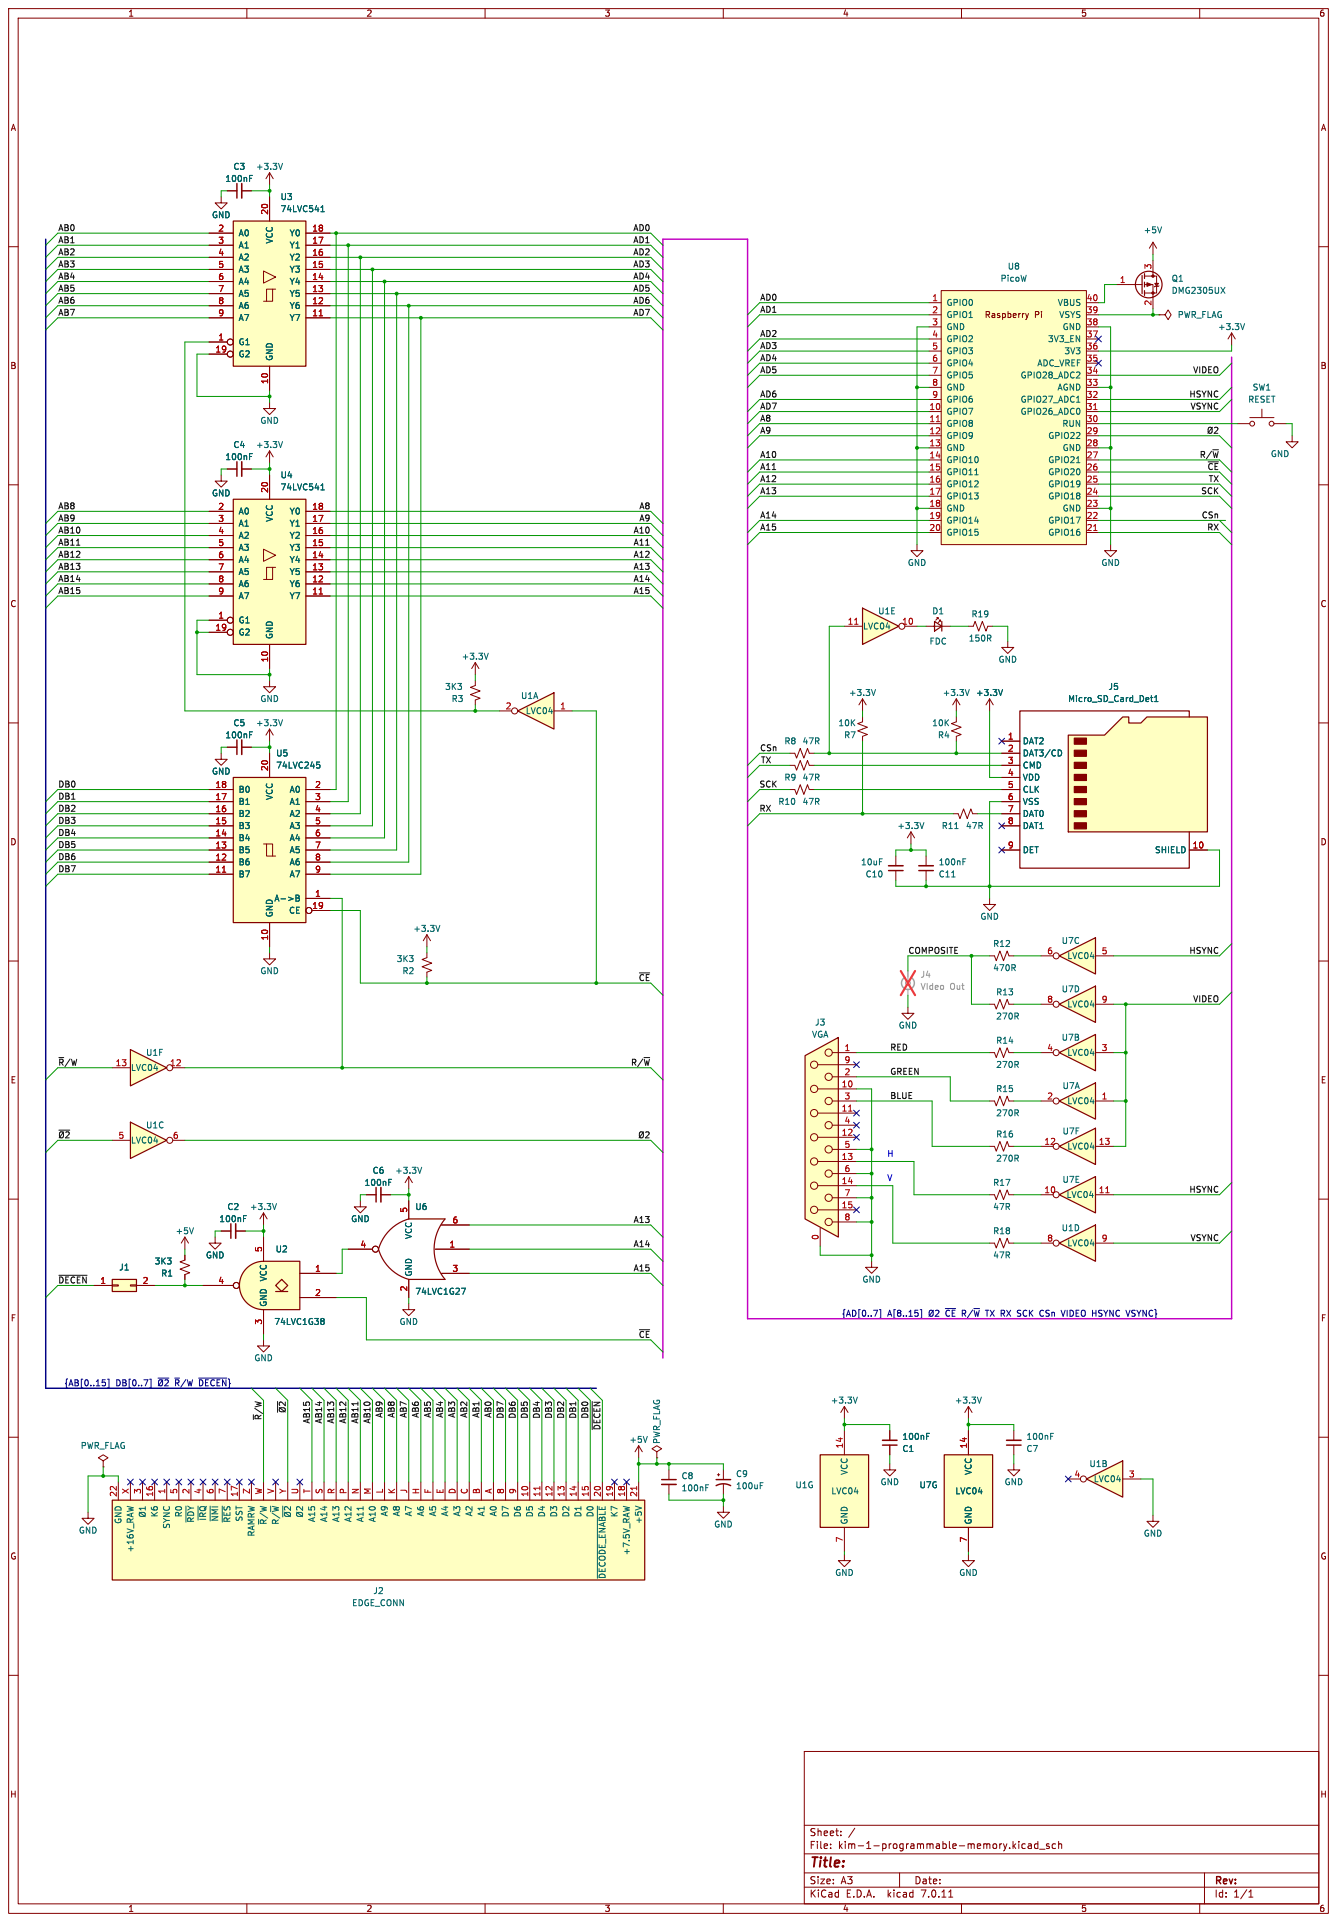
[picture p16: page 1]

7 +3.3V J5 Micro_SD_Card_Det1 DAT2 1 SHIELD 10 DAT3/CD 2 CMD 3 VDD 4 CLK 5 VSS 6 DAT0 7 DAT1 8 DET 9

1 D5 10 D4 11 D3 12 D2 13 D1 14 D0 15 K6 16 SST 17 +7.5V_RAW 18 K7 19 ~{RDY}2 ~{DECODE_ENABLE}20 +5V 21 GND 22 þÿØ1

Id: 1/1 Title: File: kim-1-programmable-memory.kicad_sch Sheet: /

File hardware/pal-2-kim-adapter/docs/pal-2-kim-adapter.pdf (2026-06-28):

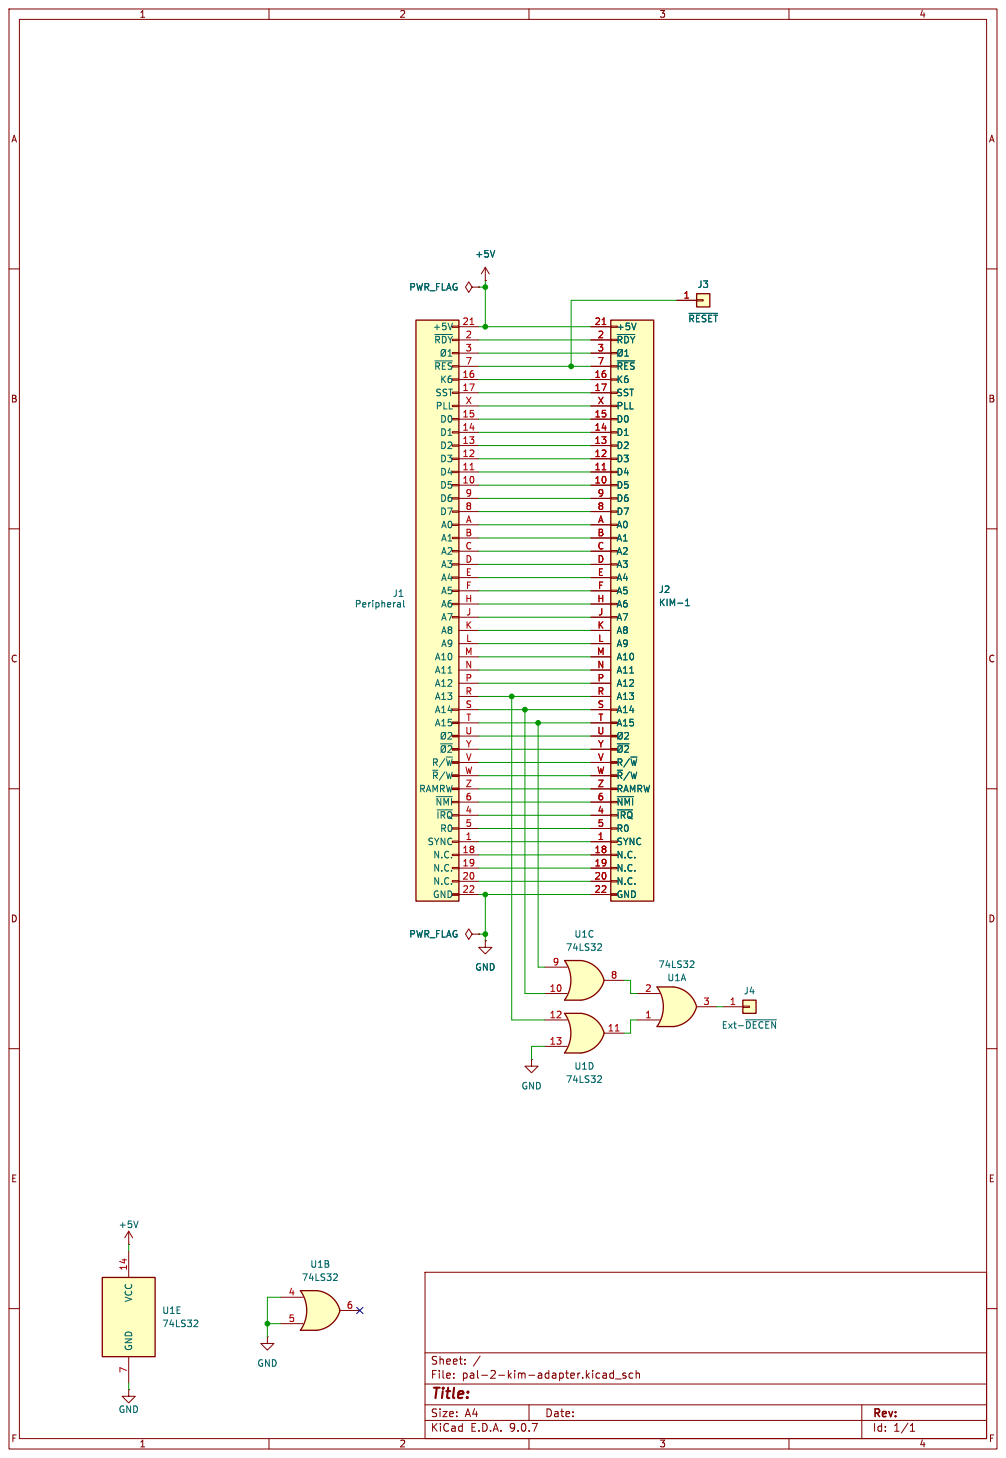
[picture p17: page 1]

A14 S
A15 T
þÿØ2 U
þÿ~{Ø2} Y R/~{W} V

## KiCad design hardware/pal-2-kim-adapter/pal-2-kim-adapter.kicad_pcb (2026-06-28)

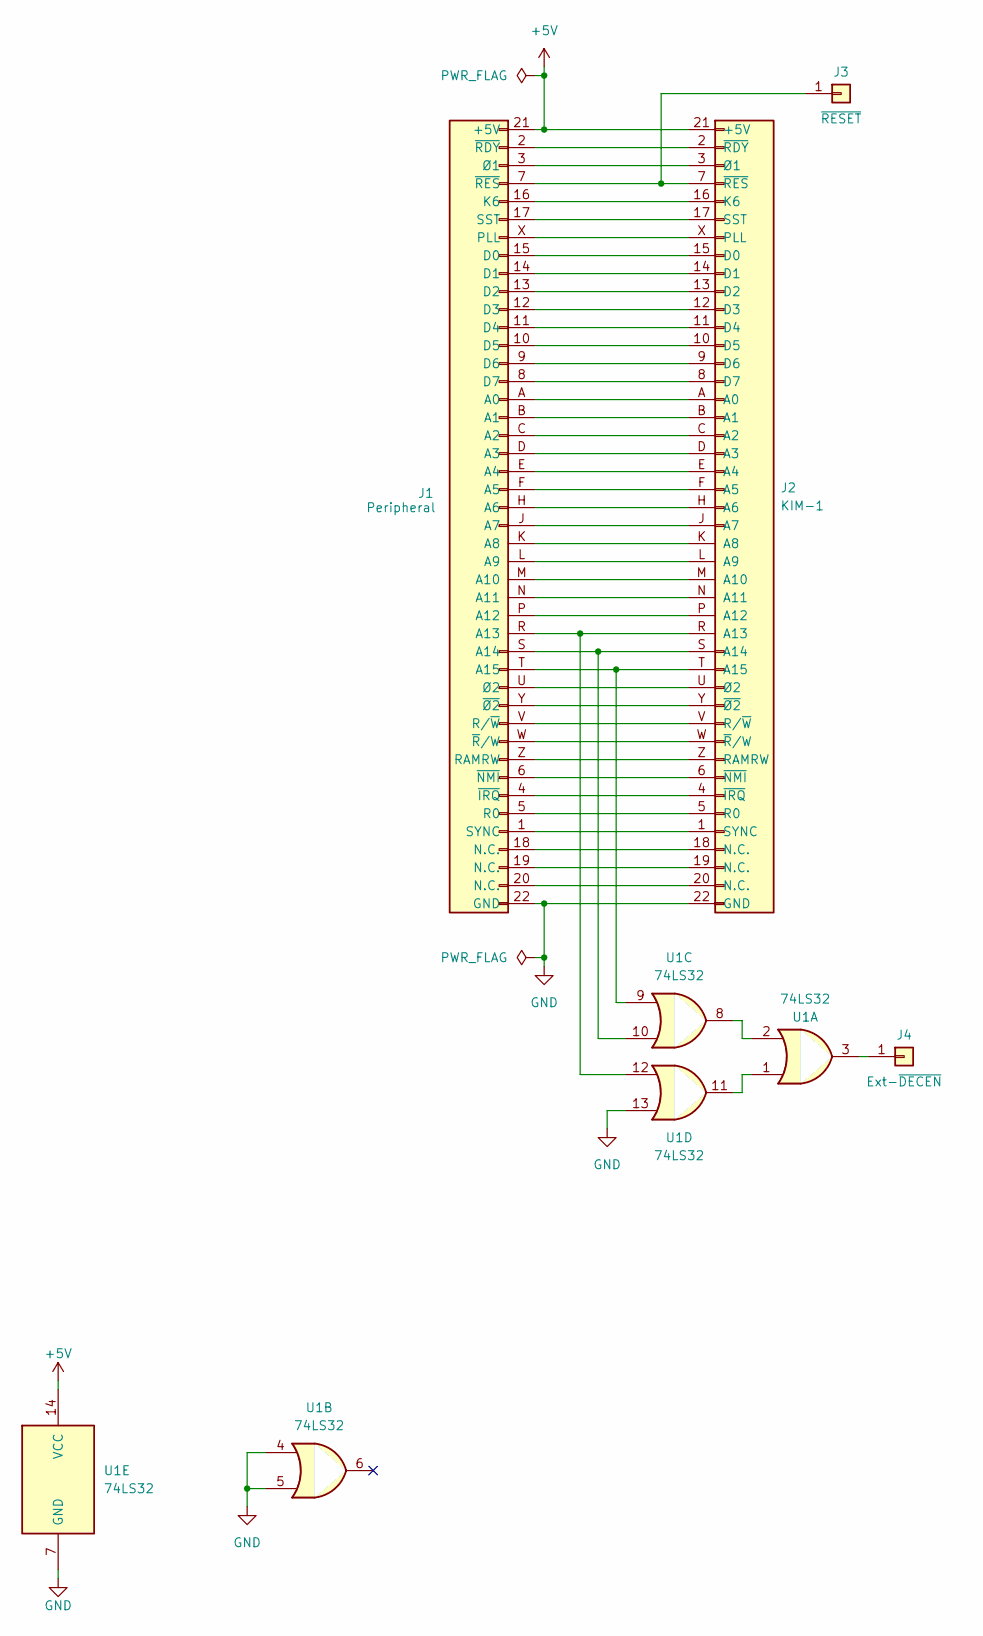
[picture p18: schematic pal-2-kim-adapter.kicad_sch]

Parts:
J1: Peripheral; PinSocket_2x22_P2.54mm_Horizontal
J2: KIM-1; KIM_EDGE
J3: ~{RESET}; PinHeader_1x01_P2.54mm_Horizontal
J4: Ext-~{DECEN}; PinHeader_1x01_P2.54mm_Vertical
U1: 74LS32; DIP-14_W7.62mm

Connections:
+5V: J1.21 (+5V), J2.21 (+5V), U1.14 (VCC)
GND: J1.22 (GND), J2.22 (GND), U1.4, U1.5, U1.7 (GND), U1.13
unnamed: J1.A (A0), J2.A (A0)
unnamed: J1.B (A1), J2.B (A1)
unnamed: J1.C (A2), J2.C (A2)
unnamed: J1.D (A3), J2.D (A3)
unnamed: J1.E (A4), J2.E (A4)
unnamed: J1.F (A5), J2.F (A5)
unnamed: J1.H (A6), J2.H (A6)
unnamed: J1.J (A7), J2.J (A7)
unnamed: J1.K (A8), J2.K (A8)
unnamed: J1.L (A9), J2.L (A9)
unnamed: J1.M (A10), J2.M (A10)
unnamed: J1.N (A11), J2.N (A11)
unnamed: J1.P (A12), J2.P (A12)
unnamed: J1.R (A13), J2.R (A13), U1.12
unnamed: J1.S (A14), J2.S (A14), U1.10
unnamed: J1.T (A15), J2.T (A15), U1.9
unnamed: J1.15 (D0), J2.15 (D0)
unnamed: J1.14 (D1), J2.14 (D1)
unnamed: J1.13 (D2), J2.13 (D2)
unnamed: J1.12 (D3), J2.12 (D3)
unnamed: J1.11 (D4), J2.11 (D4)
unnamed: J1.10 (D5), J2.10 (D5)
unnamed: J1.9 (D6), J2.9 (D6)
unnamed: J1.8 (D7), J2.8 (D7)
unnamed: J1.16 (K6), J2.16 (K6)
unnamed: J1.18 (N.C.), J2.18 (N.C.)
unnamed: J1.19 (N.C.), J2.19 (N.C.)
unnamed: J1.20 (N.C.), J2.20 (N.C.)
unnamed: J1.X (PLL), J2.X (PLL)
unnamed: J1.5 (R0), J2.5 (R0)
unnamed: J1.Z (RAMRW), J2.Z (RAMRW)
unnamed: J1.V (R/~W), J2.V (R/~W)
unnamed: J1.17 (SST), J2.17 (SST)
unnamed: J1.1 (SYNC), J2.1 (SYNC)
unnamed: J1.4 (~IRQ), J2.4 (~IRQ)
unnamed: J1.6 (~NMI), J2.6 (~NMI)
unnamed: J1.2 (~RDY), J2.2 (~RDY)
unnamed: J1.7 (~RES), J2.7 (~RES), J3.1
unnamed: J1.W (~R/W), J2.W (~R/W)
unnamed: J1.Y (~Ø2), J2.Y (~Ø2)
unnamed: J1.3 (Ø1), J2.3 (Ø1)
unnamed: J1.U (Ø2), J2.U (Ø2)
unnamed: J4.1, U1.3
unnamed: U1.1, U1.11
unnamed: U1.2, U1.8

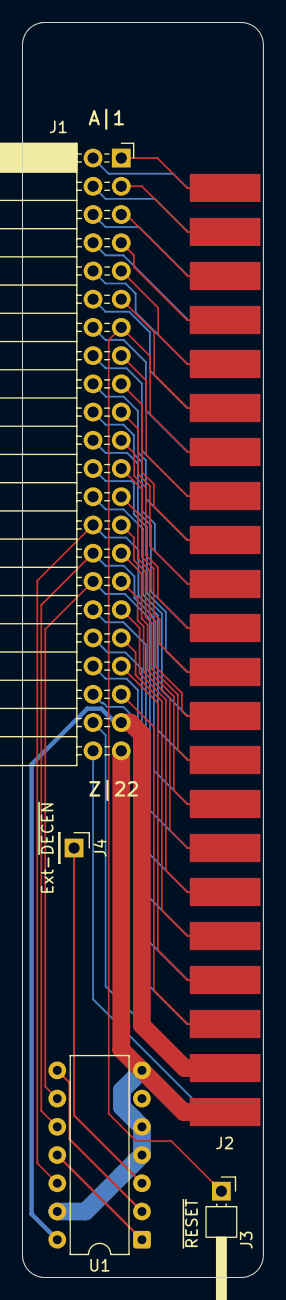
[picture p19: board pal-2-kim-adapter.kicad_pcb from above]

Board: 2 copper layers, 21.7 x 112.9 mm, 5 parts (0 on the bottom side), 47 nets.

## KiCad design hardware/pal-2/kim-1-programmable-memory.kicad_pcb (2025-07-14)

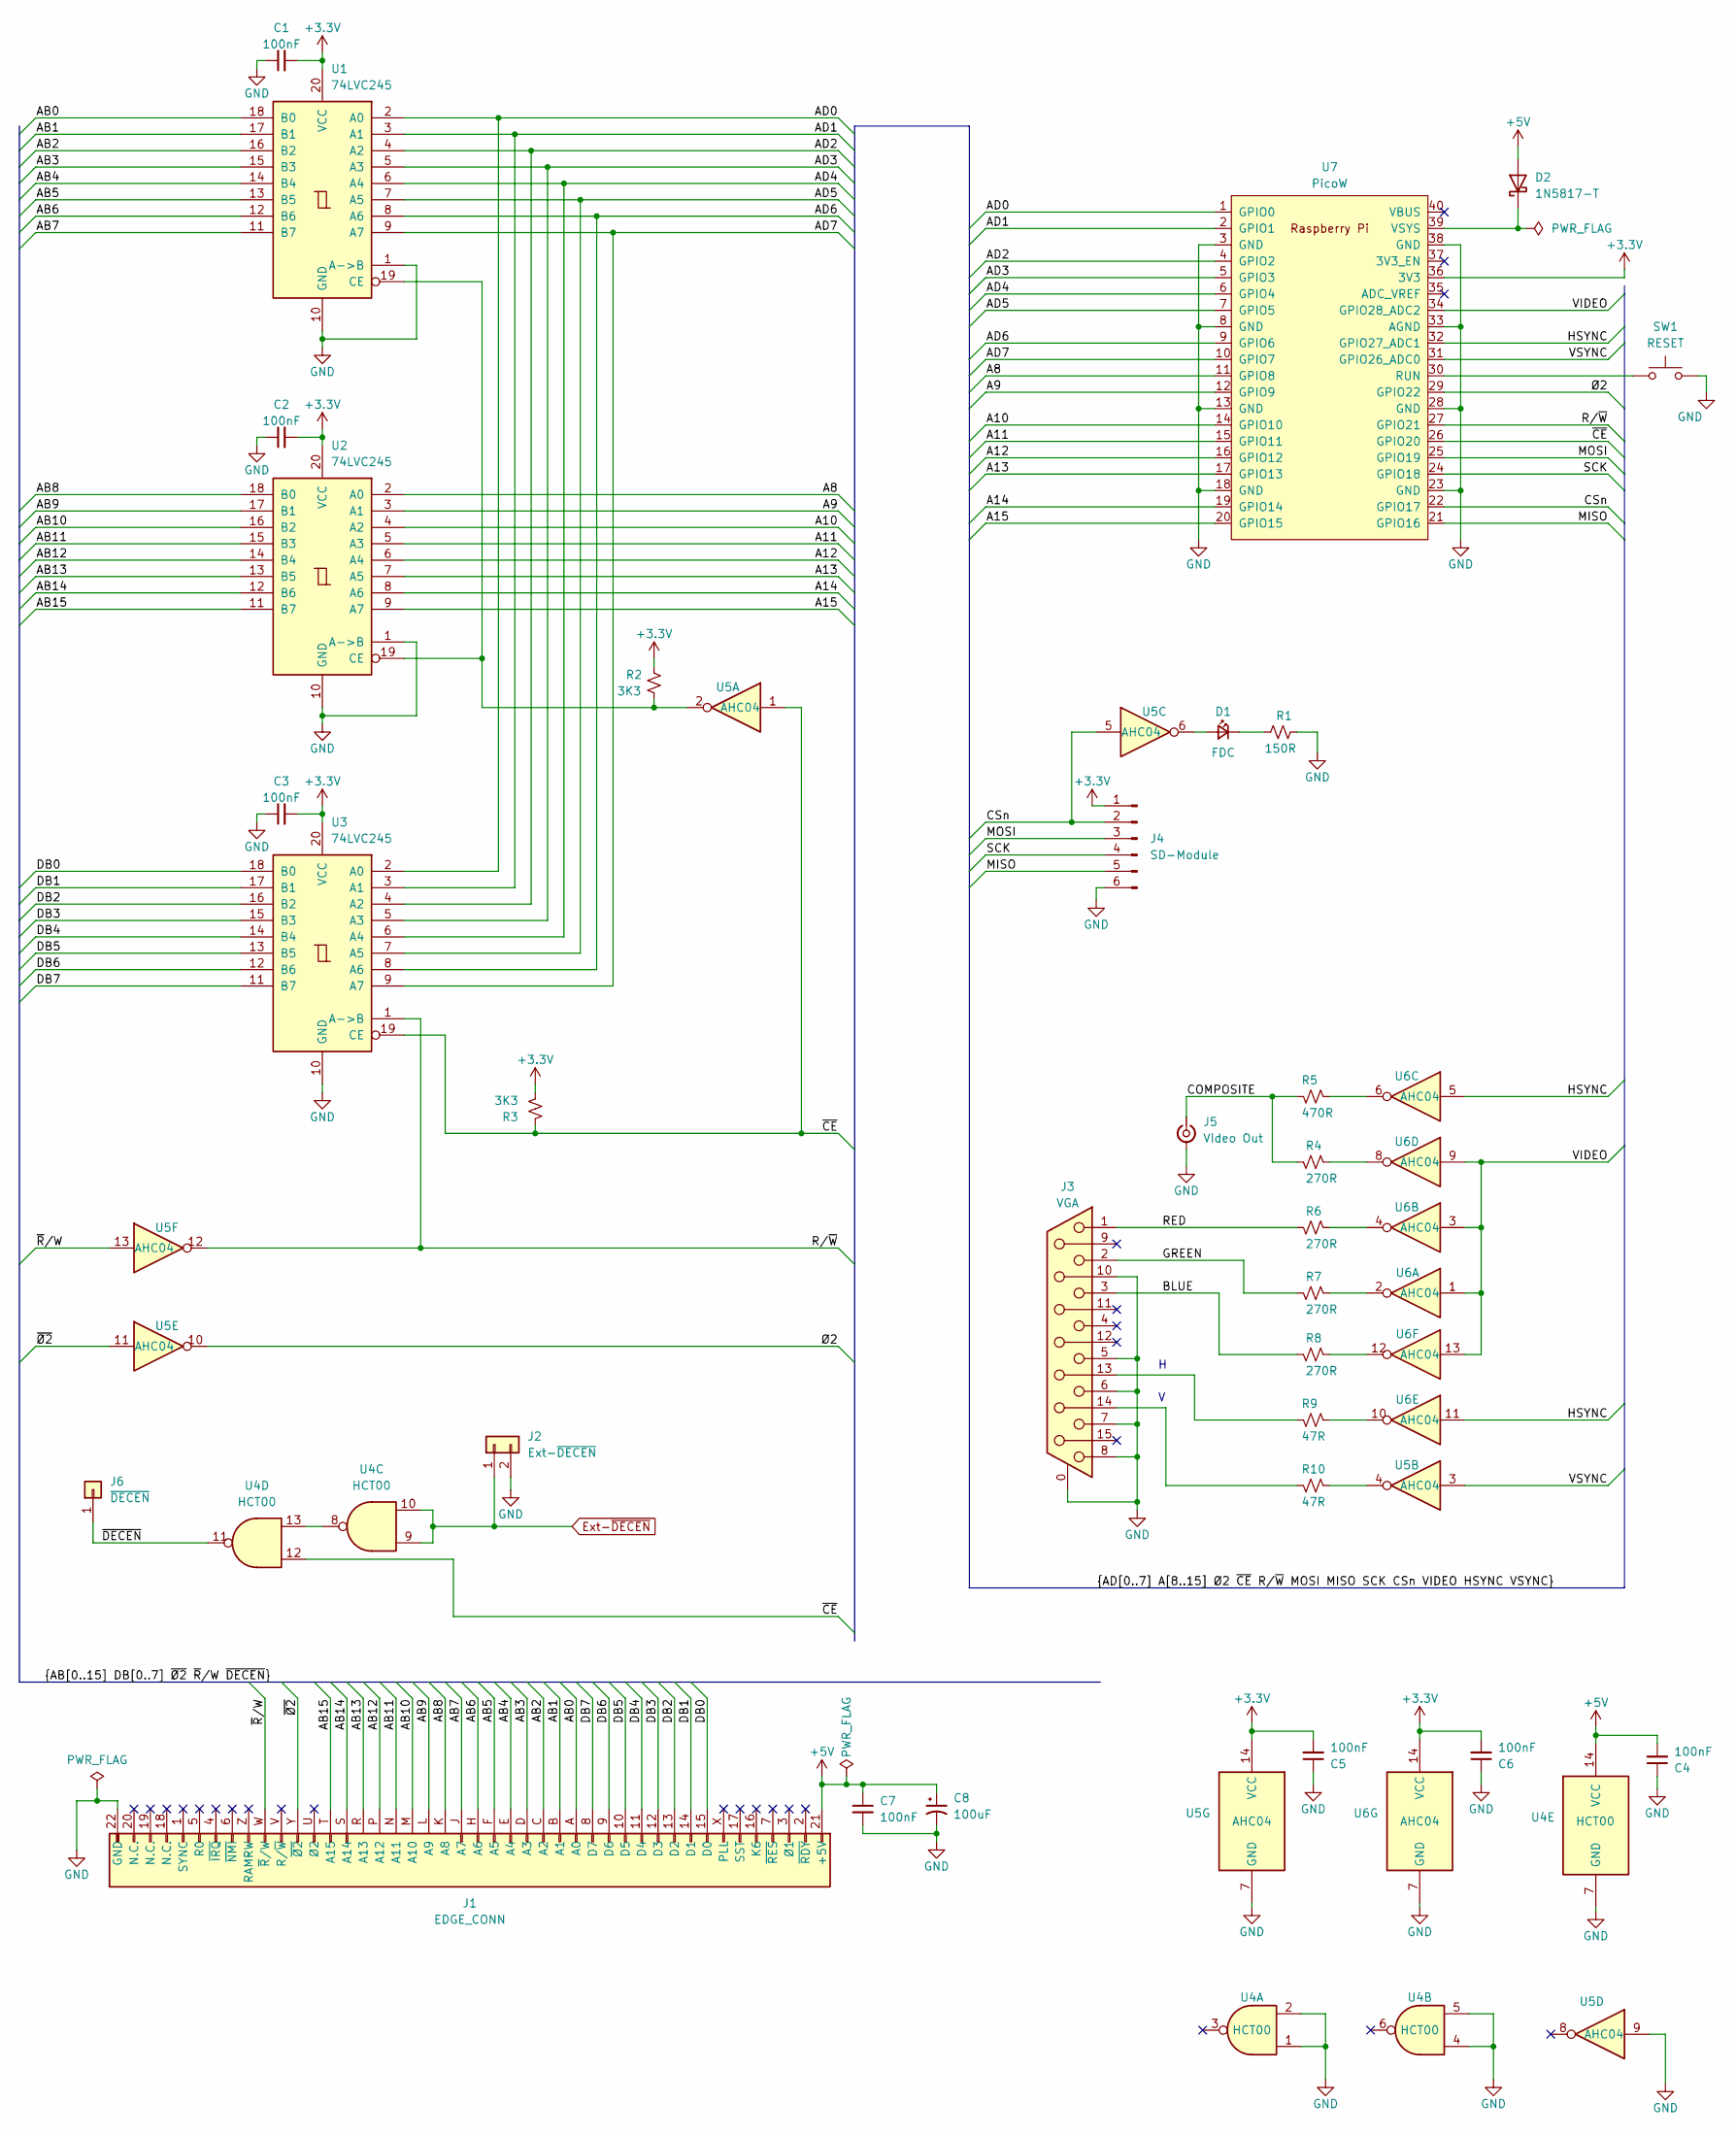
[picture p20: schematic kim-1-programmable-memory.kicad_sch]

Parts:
C1: 100nF; C_Disc_D5.0mm_W2.5mm_P5.00mm; MPN C14663
C2, C3, C4, C5, C6: 100nF; C_Disc_D5.0mm_W2.5mm_P5.00mm; LCSC C14663
C7: 100nF; C_Disc_D5.0mm_W2.5mm_P5.00mm; LCSC C28233
C8: 100uF; CP_Axial_L10.0mm_D6.0mm_P15.00mm_Horizontal; LCSC C178540
D1: FDC; LED_D3.0mm_Clear; LCSC C2286
D2: 1N5817-T; D_DO-41_SOD81_P7.62mm_Horizontal
J1: EDGE_CONN; PinHeader_2x22_P2.54mm_Horizontal
J2: Ext-~{DECEN}; PinHeader_1x02_P2.54mm_Vertical
J3: VGA; DSUB-15-HD_Female_Horizontal_P2.29x1.98mm_EdgePinOffset3.03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; LCSC C711364
J4: SD-Module; SD_Module_Small
J5: VIdeo Out; CUI_RCJ-014
J6: ~{DECEN}; PinHeader_1x01_P2.54mm_Vertical
R1: 150R; R_Axial_DIN0207_L6.3mm_D2.5mm_P7.62mm_Horizontal; LCSC C22775
R2, R3: 3K3; R_Axial_DIN0207_L6.3mm_D2.5mm_P7.62mm_Horizontal; LCSC C22978
R4, R6, R7, R8: 270R; R_Axial_DIN0207_L6.3mm_D2.5mm_P7.62mm_Horizontal; LCSC C22966
R5: 470R; R_Axial_DIN0207_L6.3mm_D2.5mm_P7.62mm_Horizontal; LCSC C23179
R9, R10: 47R; R_Axial_DIN0207_L6.3mm_D2.5mm_P7.62mm_Horizontal; LCSC C23182
SW1: RESET; SW_PUSH_6mm; LCSC C455245
U1, U2, U3: 74LVC245; DIP-20_W7.62mm_Socket; LCSC C571201
U4: HCT00; DIP-14_W7.62mm_Socket
U5, U6: AHC04; DIP-14_W7.62mm_Socket; LCSC C485074
U7: PicoW; RPi_PicoW_SMD_TH

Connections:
+3.3V: C1.2, C2.2, C3.2, C5.2, C6.2, J4.1, R2.1, R3.2, U1.20 (VCC), U2.20 (VCC), U3.20 (VCC), U5.14 (VCC), U6.14 (VCC), U7.36 (3V3)
+5V: C4.2, C7.1, C8.1, D2.2 (A), J1.21 (+5V), U4.14 (VCC)
/A8: U2.2 (A0), U7.11 (GPIO8)
/A9: U2.3 (A1), U7.12 (GPIO9)
/A10: U2.4 (A2), U7.14 (GPIO10)
/A11: U2.5 (A3), U7.15 (GPIO11)
/A12: U2.6 (A4), U7.16 (GPIO12)
/A13: U2.7 (A5), U7.17 (GPIO13)
/A14: U2.8 (A6), U7.19 (GPIO14)
/A15: U2.9 (A7), U7.20 (GPIO15)
/AB0: J1.A (A0), U1.18 (B0)
/AB1: J1.B (A1), U1.17 (B1)
/AB2: J1.C (A2), U1.16 (B2)
/AB3: J1.D (A3), U1.15 (B3)
/AB4: J1.E (A4), U1.14 (B4)
/AB5: J1.F (A5), U1.13 (B5)
/AB6: J1.H (A6), U1.12 (B6)
/AB7: J1.J (A7), U1.11 (B7)
/AB8: J1.K (A8), U2.18 (B0)
/AB9: J1.L (A9), U2.17 (B1)
/AB10: J1.M (A10), U2.16 (B2)
/AB11: J1.N (A11), U2.15 (B3)
/AB12: J1.P (A12), U2.14 (B4)
/AB13: J1.R (A13), U2.13 (B5)
/AB14: J1.S (A14), U2.12 (B6)
/AB15: J1.T (A15), U2.11 (B7)
/AD0: U1.2 (A0), U3.2 (A0), U7.1 (GPIO0)
/AD1: U1.3 (A1), U3.3 (A1), U7.2 (GPIO1)
/AD2: U1.4 (A2), U3.4 (A2), U7.4 (GPIO2)
/AD3: U1.5 (A3), U3.5 (A3), U7.5 (GPIO3)
/AD4: U1.6 (A4), U3.6 (A4), U7.6 (GPIO4)
/AD5: U1.7 (A5), U3.7 (A5), U7.7 (GPIO5)
/AD6: U1.8 (A6), U3.8 (A6), U7.9 (GPIO6)
/AD7: U1.9 (A7), U3.9 (A7), U7.10 (GPIO7)
/BLUE: J3.3, R8.1
/COMPOSITE: J5.1 (In), R4.1, R5.1
/CSn: J4.2, U5.5, U7.22 (GPIO17)
/DB0: J1.15 (D0), U3.18 (B0)
/DB1: J1.14 (D1), U3.17 (B1)
/DB2: J1.13 (D2), U3.16 (B2)
/DB3: J1.12 (D3), U3.15 (B3)
/DB4: J1.11 (D4), U3.14 (B4)
/DB5: J1.10 (D5), U3.13 (B5)
/DB6: J1.9 (D6), U3.12 (B6)
/DB7: J1.8 (D7), U3.11 (B7)
/GREEN: J3.2, R7.1
/HSYNC: U6.5, U6.11, U7.32 (GPIO27_ADC1)
/MISO: J4.5, U7.21 (GPIO16)
/MOSI: J4.3, U7.25 (GPIO19)
/RED: J3.1, R6.1
/R/~W: U3.1 (A->B), U5.12, U7.27 (GPIO21)
/SCK: J4.4, U7.24 (GPIO18)
/VIDEO: U6.1, U6.3, U6.9, U6.13, U7.34 (GPIO28_ADC2)
/VSYNC: U5.3, U7.31 (GPIO26_ADC0)
/~CE: R3.1, U3.19 (CE), U4.12, U5.1, U7.26 (GPIO20)
/~DECEN: J6.1, U4.11
/~R/W: J1.W (~R/W), U5.13
/~Ø2: J1.Y (~Ø2), U5.11
/Ø2: U5.10, U7.29 (GPIO22)
Ext-~DECEN: J2.1, U4.9, U4.10
GND: C1.1, C2.1, C3.1, C4.1, C5.1, C6.1, C7.2, C8.2, J1.22 (GND), J2.2, J3.0 (PAD), J3.5, J3.6, J3.7, J3.8, J3.10, J4.6, J5.2 (Ext), R1.1, SW1.2, U1.1 (A->B), U1.10 (GND), U2.1 (A->B), U2.10 (GND), U3.10 (GND), U4.1, U4.2, U4.4, U4.5, U4.7 (GND), U5.7 (GND), U5.9, U6.7 (GND), U7.3 (GND), U7.8 (GND), U7.13 (GND), U7.18 (GND), U7.23 (GND), U7.28 (GND), U7.33 (AGND), U7.38 (GND)
unnamed: D1.2 (A), U5.6
unnamed: D1.1 (K), R1.2
unnamed: D2.1 (K), U7.39 (VSYS)
unnamed: J3.13, R9.1
unnamed: J3.14, R10.1
unnamed: R4.2, U6.8
unnamed: R5.2, U6.6
unnamed: R6.2, U6.4
unnamed: R7.2, U6.2
unnamed: R8.2, U6.12
unnamed: R9.2, U6.10
unnamed: R10.2, U5.4
unnamed: R2.2, U1.19 (CE), U2.19 (CE), U5.2
unnamed: U4.8, U4.13
unnamed: SW1.1, U7.30 (RUN)

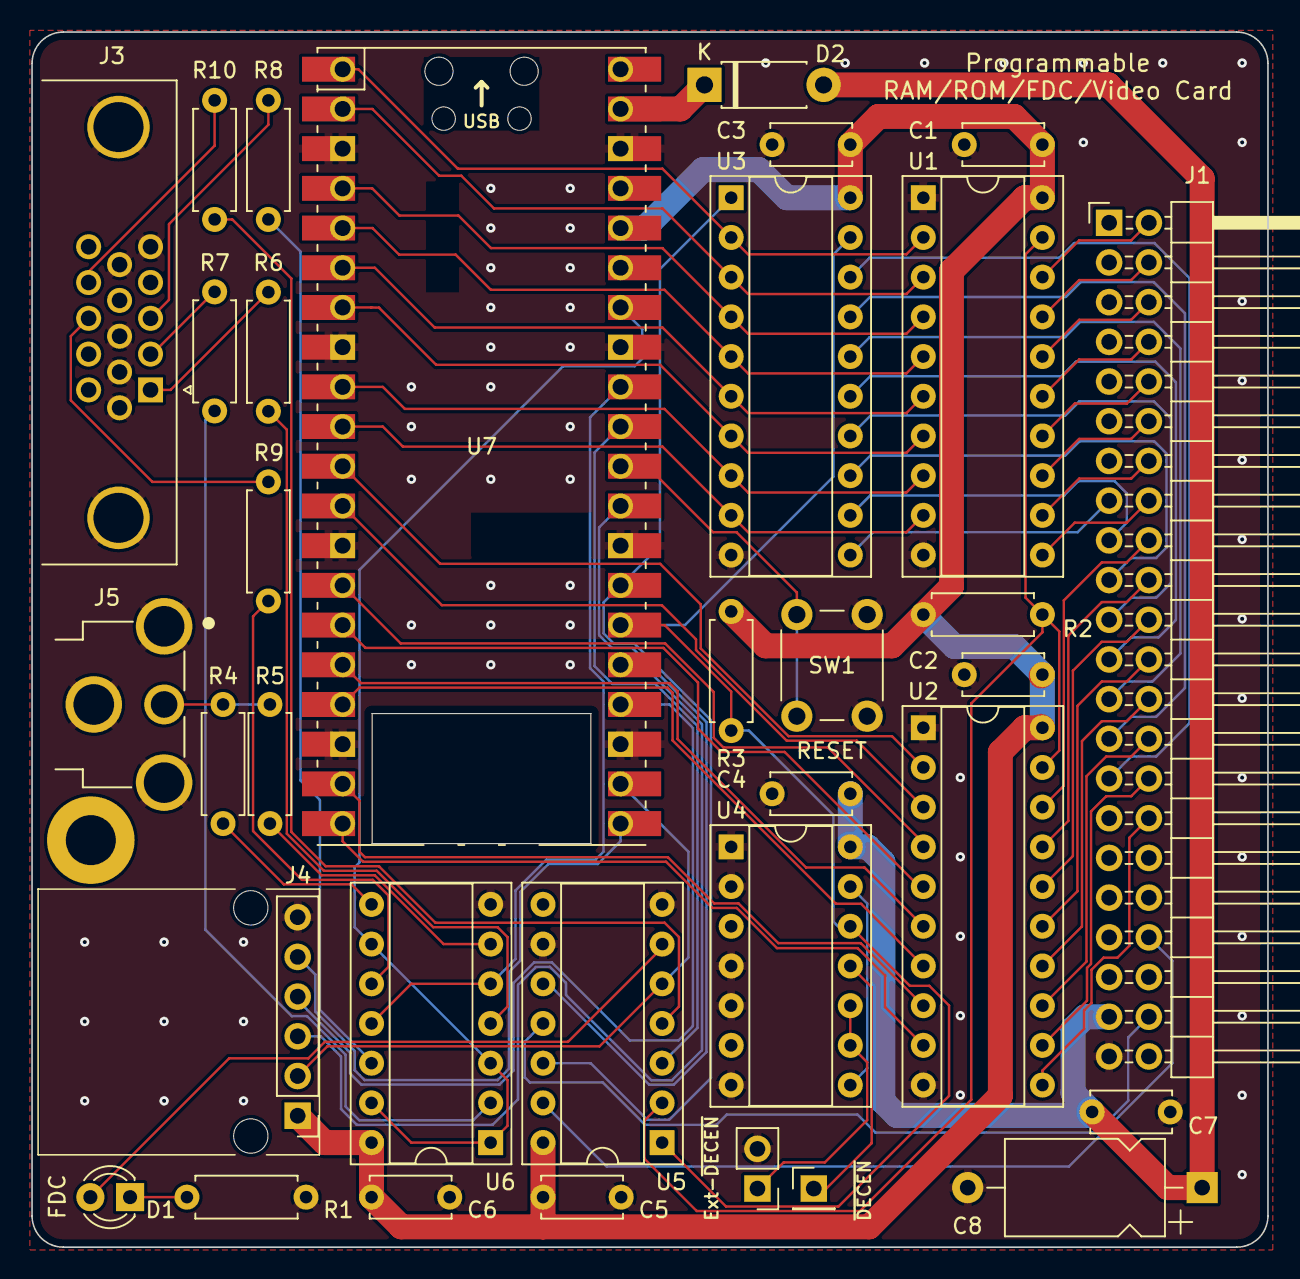
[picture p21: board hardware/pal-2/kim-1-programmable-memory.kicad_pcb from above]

Board: 2 copper layers, 79.1 x 77.7 mm, 34 parts (0 on the bottom side), 76 nets.

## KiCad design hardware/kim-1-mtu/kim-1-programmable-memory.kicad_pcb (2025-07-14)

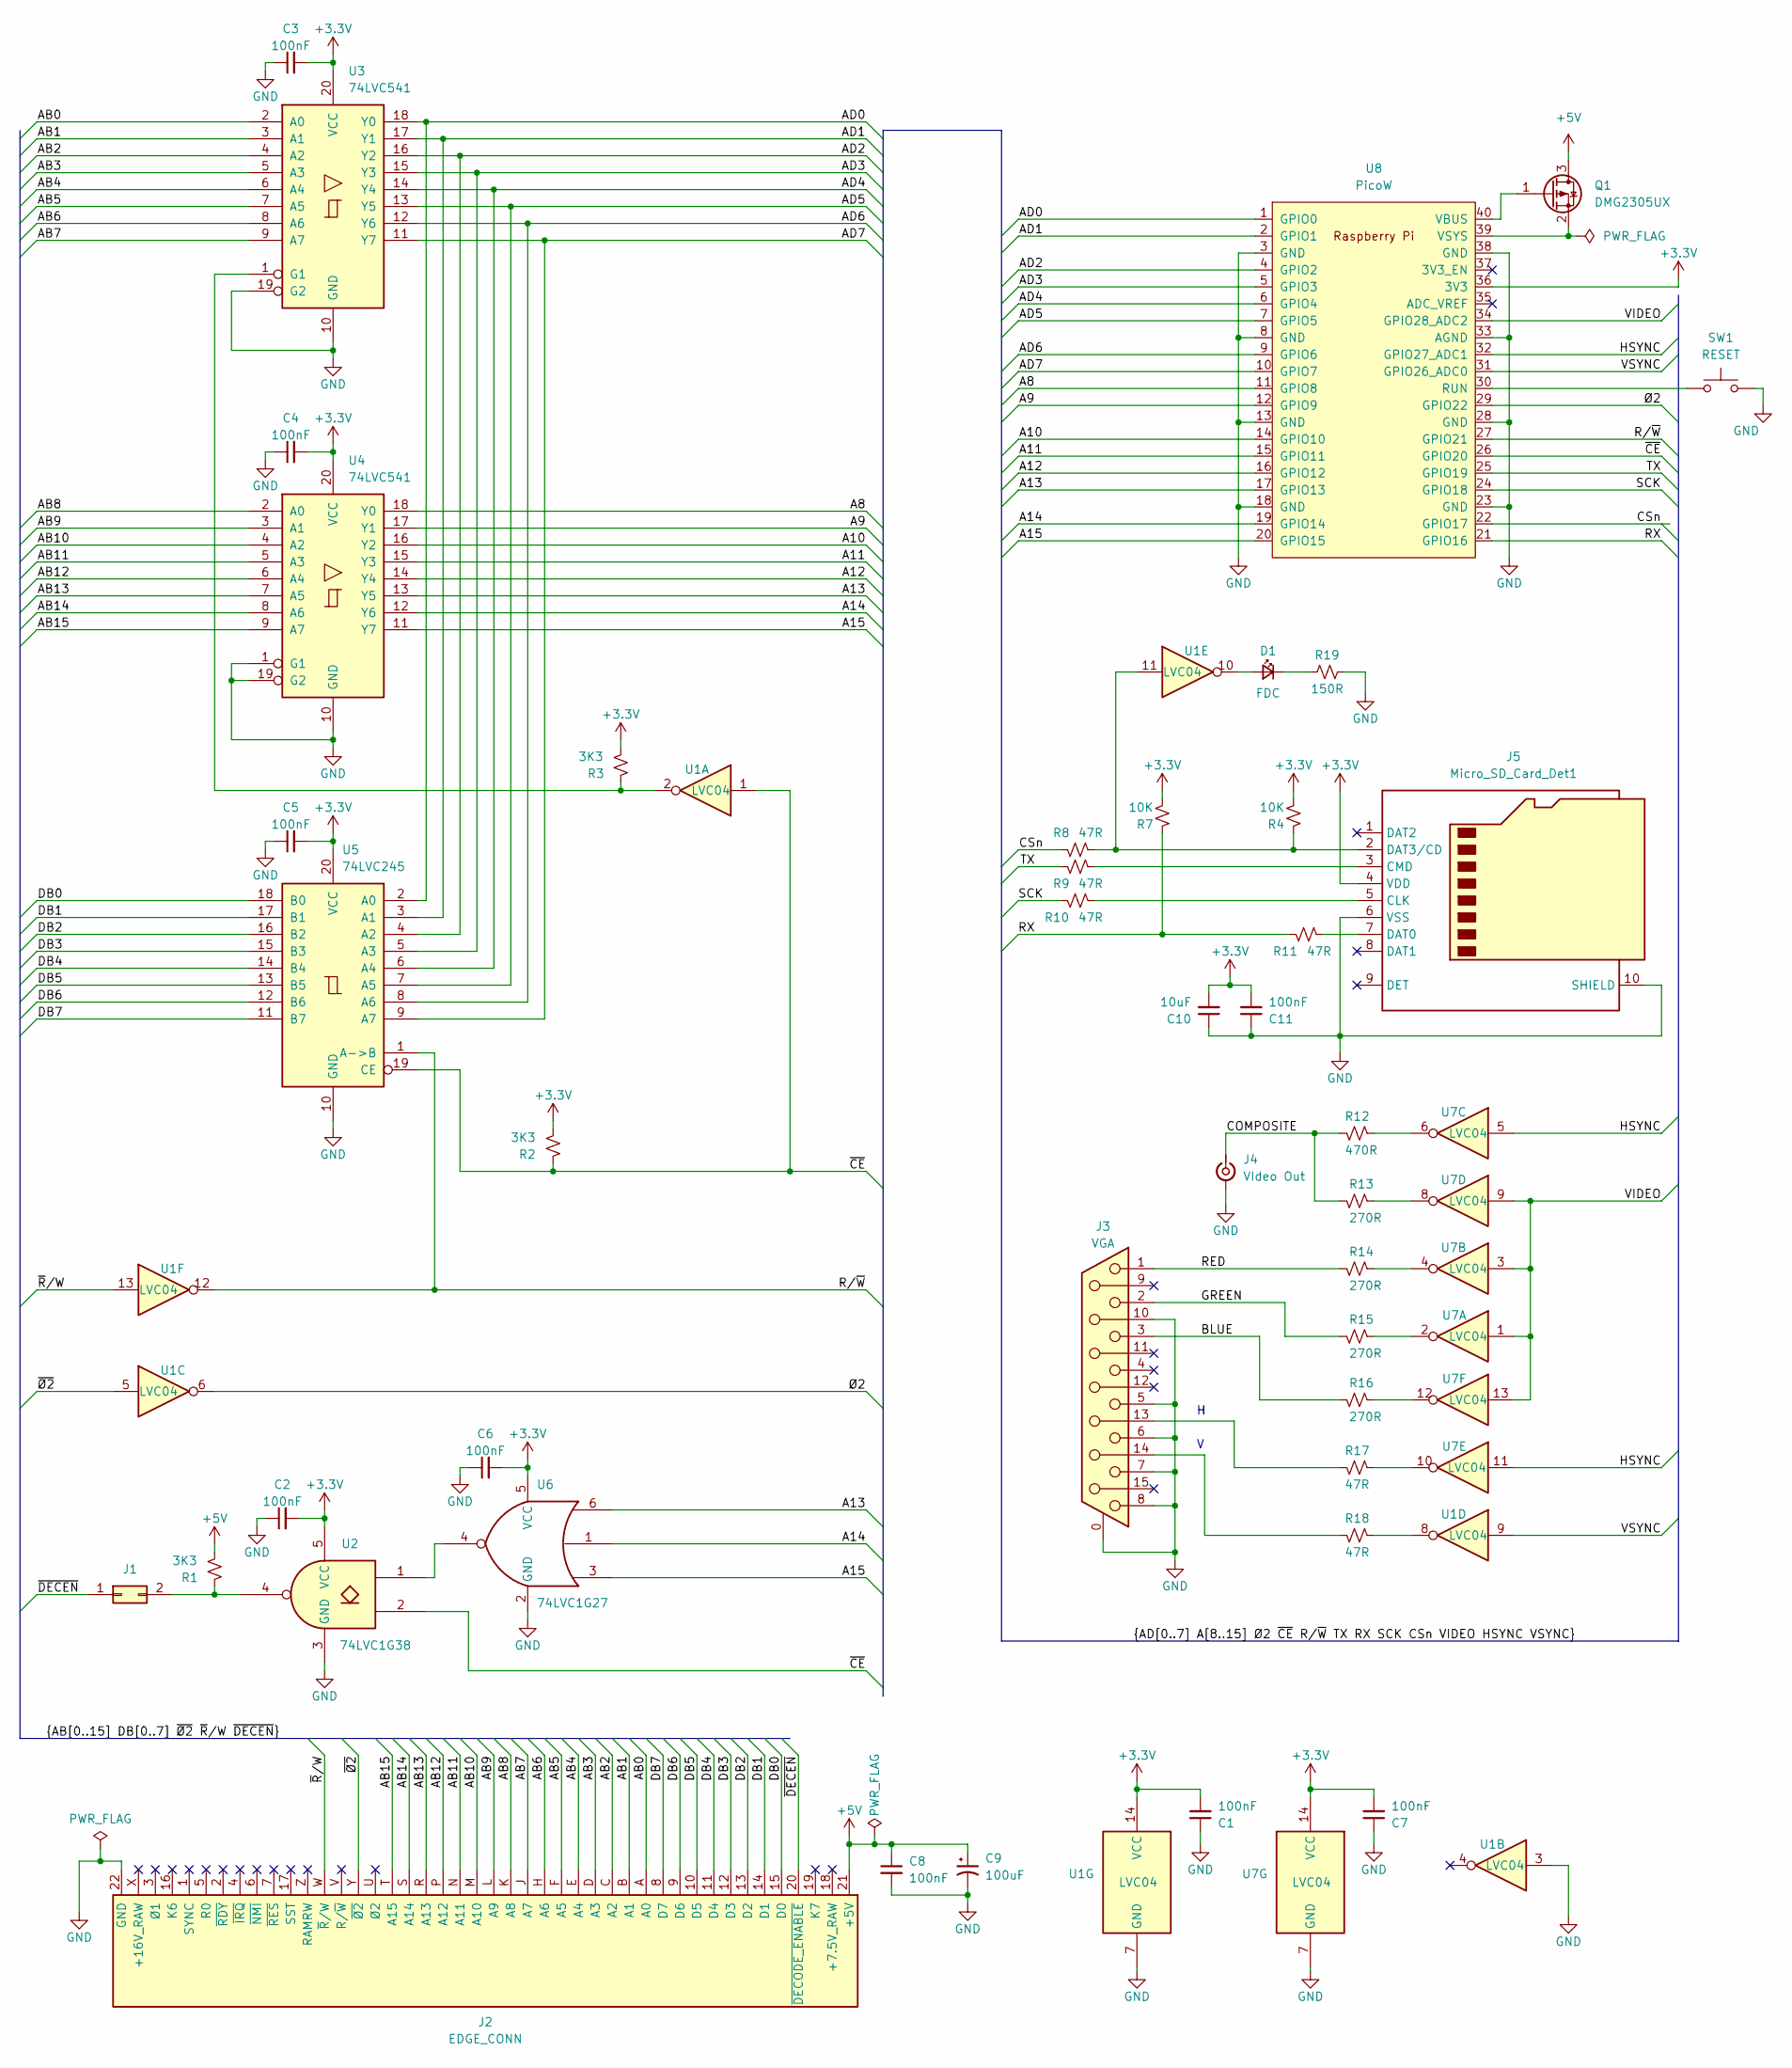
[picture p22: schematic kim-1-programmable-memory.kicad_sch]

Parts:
C1, C2, C4, C5, C6, C7, C11: 100nF; C_0603_1608Metric_Pad1.08x0.95mm_HandSolder; LCSC C14663
C3: 100nF; C_0603_1608Metric_Pad1.08x0.95mm_HandSolder; MPN C14663
C8: 100nF; C_0805_2012Metric_Pad1.18x1.45mm_HandSolder; LCSC C28233
C9: 100uF; CP_Elec_6.3x5.9; LCSC C178540
C10: 10uF; C_0603_1608Metric_Pad1.08x0.95mm_HandSolder; LCSC C96446
D1: FDC; LED_0603_1608Metric_Pad1.05x0.95mm_HandSolder; LCSC C2286
J1: Conn_02x01; PinHeader_1x02_P2.54mm_Vertical
J2: EDGE_CONN
J3: VGA; DSUB-15-HD_Female_Horizontal_P2.29x1.98mm_EdgePinOffset3.03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; LCSC C711364
J4: VIdeo Out; CUI_RCJ-014
J5: Micro_SD_Card_Det1; SD_Card_Holder_SMD_WQ21801-B2180-7F; LCSC C266620
Q1: DMG2305UX; SOT-23; LCSC C150470
R1, R2, R3: 3K3; R_0603_1608Metric_Pad0.98x0.95mm_HandSolder; LCSC C22978
R4, R7: 10K; R_0603_1608Metric_Pad0.98x0.95mm_HandSolder; LCSC C25804
R8, R9, R10, R11, R17, R18: 47R; R_0603_1608Metric_Pad0.98x0.95mm_HandSolder; LCSC C23182
R12: 470R; R_0603_1608Metric_Pad0.98x0.95mm_HandSolder; LCSC C23179
R13, R14, R15, R16: 270R; R_0603_1608Metric_Pad0.98x0.95mm_HandSolder; LCSC C22966
R19: 150R; R_0603_1608Metric_Pad0.98x0.95mm_HandSolder; LCSC C22775
SW1: RESET; SW_SPST_TL3305A; LCSC C455245
U1, U7: LVC04; SOIC-14_3.9x8.7mm_P1.27mm; LCSC C485074
U2: 74LVC1G38; SOT-23-5_HandSoldering; LCSC C2867613
U3, U4: 74LVC541; SOIC-20W_7.5x12.8mm_P1.27mm; LCSC C2652110
U5: 74LVC245; SOIC-20W_7.5x12.8mm_P1.27mm; LCSC C571201
U6: 74LVC1G27; SOT-23-6_Handsoldering; LCSC C128410
U8: PicoW; RPi_PicoW_SMD

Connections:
+3.3V: C1.2, C2.2, C3.2, C4.2, C5.2, C6.2, C7.2, C10.2, C11.2, J5.4 (VDD), R2.2, R3.2, R4.2, R7.2, U1.14 (VCC), U2.5 (VCC), U3.20 (VCC), U4.20 (VCC), U5.20 (VCC), U6.5 (VCC), U7.14 (VCC), U8.36 (3V3)
+5V: C8.1, C9.1, J2.21 (+5V), Q1.3 (D), R1.2
/A8: U4.18 (Y0), U8.11 (GPIO8)
/A9: U4.17 (Y1), U8.12 (GPIO9)
/A10: U4.16 (Y2), U8.14 (GPIO10)
/A11: U4.15 (Y3), U8.15 (GPIO11)
/A12: U4.14 (Y4), U8.16 (GPIO12)
/A13: U4.13 (Y5), U6.6, U8.17 (GPIO13)
/A14: U4.12 (Y6), U6.1, U8.19 (GPIO14)
/A15: U4.11 (Y7), U6.3, U8.20 (GPIO15)
/AB0: J2.A (A0), U3.2 (A0)
/AB1: J2.B (A1), U3.3 (A1)
/AB2: J2.C (A2), U3.4 (A2)
/AB3: J2.D (A3), U3.5 (A3)
/AB4: J2.E (A4), U3.6 (A4)
/AB5: J2.F (A5), U3.7 (A5)
/AB6: J2.H (A6), U3.8 (A6)
/AB7: J2.J (A7), U3.9 (A7)
/AB8: J2.K (A8), U4.2 (A0)
/AB9: J2.L (A9), U4.3 (A1)
/AB10: J2.M (A10), U4.4 (A2)
/AB11: J2.N (A11), U4.5 (A3)
/AB12: J2.P (A12), U4.6 (A4)
/AB13: J2.R (A13), U4.7 (A5)
/AB14: J2.S (A14), U4.8 (A6)
/AB15: J2.T (A15), U4.9 (A7)
/AD0: U3.18 (Y0), U5.2 (A0), U8.1 (GPIO0)
/AD1: U3.17 (Y1), U5.3 (A1), U8.2 (GPIO1)
/AD2: U3.16 (Y2), U5.4 (A2), U8.4 (GPIO2)
/AD3: U3.15 (Y3), U5.5 (A3), U8.5 (GPIO3)
/AD4: U3.14 (Y4), U5.6 (A4), U8.6 (GPIO4)
/AD5: U3.13 (Y5), U5.7 (A5), U8.7 (GPIO5)
/AD6: U3.12 (Y6), U5.8 (A6), U8.9 (GPIO6)
/AD7: U3.11 (Y7), U5.9 (A7), U8.10 (GPIO7)
/BLUE: J3.3, R16.1
/COMPOSITE: J4.1 (In), R12.1, R13.1
/CSn: R8.1, U8.22 (GPIO17)
/DB0: J2.15 (D0), U5.18 (B0)
/DB1: J2.14 (D1), U5.17 (B1)
/DB2: J2.13 (D2), U5.16 (B2)
/DB3: J2.12 (D3), U5.15 (B3)
/DB4: J2.11 (D4), U5.14 (B4)
/DB5: J2.10 (D5), U5.13 (B5)
/DB6: J2.9 (D6), U5.12 (B6)
/DB7: J2.8 (D7), U5.11 (B7)
/GREEN: J3.2, R15.1
/HSYNC: U7.5, U7.11, U8.32 (GPIO27_ADC1)
/RED: J3.1, R14.1
/RX: R7.1, R11.1, U8.21 (GPIO16)
/R/~W: U1.12, U5.1 (A->B), U8.27 (GPIO21)
/SCK: R10.1, U8.24 (GPIO18)
/TX: R9.1, U8.25 (GPIO19)
/VIDEO: U7.1, U7.3, U7.9, U7.13, U8.34 (GPIO28_ADC2)
/VSYNC: U1.9, U8.31 (GPIO26_ADC0)
/~CE: R2.1, U1.1, U2.2, U5.19 (CE), U8.26 (GPIO20)
/~DECEN: J1.1, J2.20 (~DECODE_ENABLE)
/~R/W: J2.W (~R/W), U1.13
/~Ø2: J2.Y (~Ø2), U1.5
/Ø2: U1.6, U8.29 (GPIO22)
GND: C1.1, C2.1, C3.1, C4.1, C5.1, C6.1, C7.1, C8.2, C9.2, C10.1, C11.1, J2.22 (GND), J3.0 (PAD), J3.5, J3.6, J3.7, J3.8, J3.10, J4.2 (Ext), J5.6 (VSS), J5.10 (SHIELD), R19.1, SW1.2, U1.3, U1.7 (GND), U2.3 (GND), U3.10 (GND), U3.19 (G2), U4.1 (G1), U4.10 (GND), U4.19 (G2), U5.10 (GND), U6.2 (GND), U7.7 (GND), U8.3 (GND), U8.8 (GND), U8.13 (GND), U8.18 (GND), U8.23 (GND), U8.28 (GND), U8.33 (AGND), U8.38 (GND)
unnamed: D1.2 (A), U1.10
unnamed: D1.1 (K), R19.2
unnamed: J1.2, R1.1, U2.4
unnamed: J3.13, R17.1
unnamed: J3.14, R18.1
unnamed: J5.5 (CLK), R10.2
unnamed: J5.3 (CMD), R9.2
unnamed: J5.7 (DAT0), R11.2
unnamed: J5.2 (DAT3/CD), R4.1, R8.2, U1.11
unnamed: Q1.1 (G), U8.40 (VBUS)
unnamed: Q1.2 (S), U8.39 (VSYS)
unnamed: R12.2, U7.6
unnamed: R13.2, U7.8
unnamed: R14.2, U7.4
unnamed: R15.2, U7.2
unnamed: R16.2, U7.12
unnamed: R17.2, U7.10
unnamed: R18.2, U1.8
unnamed: U2.1, U6.4
unnamed: R3.1, U1.2, U3.1 (G1)
unnamed: SW1.1, U8.30 (RUN)

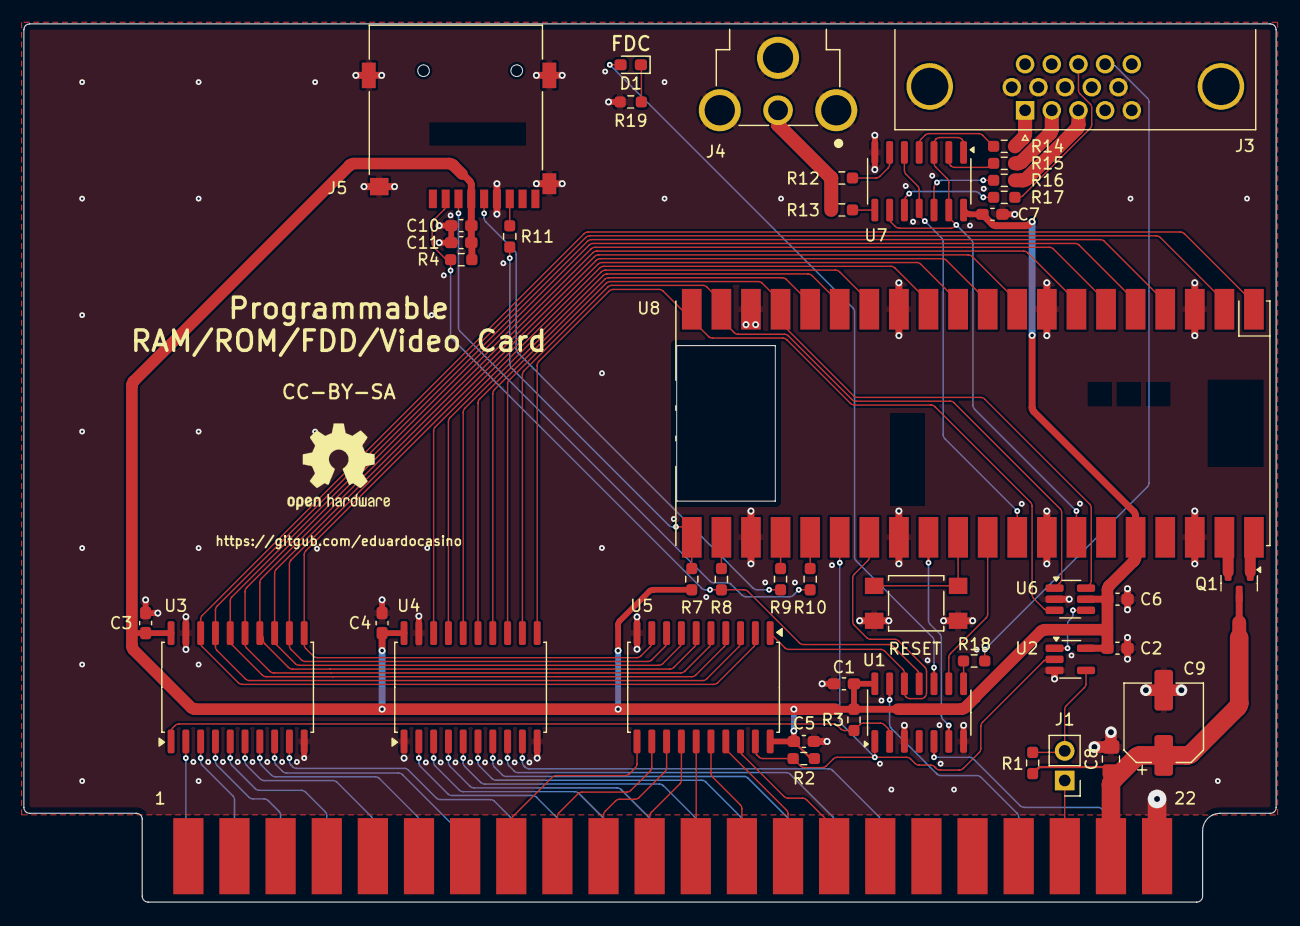
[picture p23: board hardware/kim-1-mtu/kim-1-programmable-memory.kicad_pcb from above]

Board: 2 copper layers, 107.5 x 75.4 mm, 44 parts (0 on the bottom side), 81 nets.

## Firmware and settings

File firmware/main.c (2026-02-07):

/*
 * main file for the KIM-1 Programmable Memory Board
 *   https://github.com/eduardocasino/kim-1-programmable-memory-card
 *
 *  Copyright (C) 2024 Eduardo Casino
 *
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
 * You should have received a copy of the GNU General Public License
 * along with this program; if not, write to the Free Software
 * Foundation, Inc., 51 Franklin Street, Fifth Floor, Boston,
 * MA  02110-1301, USA.
 */

#include <stdint.h>
#include <stdio.h>
#include "pico/stdlib.h"
#include "hardware/rtc.h"
#include "hardware/clocks.h"

#include "config.h"
#include "mememul.h"
#include "video.h"
#include "fdc.h"
#include "wlan.h"
#include "webserver.h"


void main( void )
{
    stdio_init_all();
    rtc_init();

    // WARNING: This implementation implementation assumes the stock 125MHz setting
    //          If overclocking, modify the PIO state machines accordingly
    //
    // Set overclock

    set_sys_clock_khz( 125000, true );                      // Ensure 125MHz clock

    // Copy default memory map from flash
    //
    config_copy_default_memory_map( &mem_map[0] );
    
    // Setup PIO State Machines, pins and DMA channels
    //
    mememul_setup( &mem_map[0] );
    video_setup( &mem_map[0] );

    // Setup disk emulation
    //
    if ( config.fdc.enabled )
    {
        fdc_setup( &mem_map[0] );
    }

    // Setup wireless network. This function only returns if connection is
    // successful.
    //
    wlan_setup();

    // Setup commands webserver. This function never returns
    //
    webserver_run();

    // If returns, its been an error
    //
    wlan_blink_fast( 4 );
}

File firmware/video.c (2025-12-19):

/*
 * Video PIO configuration for the KIM-1 Programmable Memory Board
 *   https://github.com/eduardocasino/kim-1-programmable-memory-card
 *
 *  Copyright (C) 2024 Eduardo Casino
 *
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
 * You should have received a copy of the GNU General Public License
 * along with this program; if not, write to the Free Software
 * Foundation, Inc., 51 Franklin Street, Fifth Floor, Boston,
 * MA  02110-1301, USA.
 */

/*
 * Credit to Alan Reed for his composite video implementation:
 * https://github.com/alanpreed/pico-composite-video
 * and Hunter Adams for his VGA implementation:
 * https://github.com/vha3/Hunter-Adams-RP2040-Demos/tree/master/VGA_Graphics
 */

#include "pico/stdlib.h"
#include "hardware/pio.h"
#include "hardware/dma.h"
#include "hardware/clocks.h"

#include "video.pio.h"
#include "vga.pio.h"

#include "config.h"
#include "pins.h"
#include "dmacfg.h"
#include "video.h"
#include "debug.h"

#define NTSC_SCANLINES      260
#define PAL_SCANLINES       312
#define VERT_SYNC_SCANLINES 4

#define VIDEO_LINES        200
#define VIDEO_PIX_PER_LINE 320
#define VIDEO_MEMORY_SIZE  ( VIDEO_LINES * VIDEO_PIX_PER_LINE ) / 8

// ---------- Composite video timings ----------
// Sync PIO needs 8us per instruction
#define SYNC_INTERVAL 0.000008
// Data transmits for 40us
#define DATA_INTERVAL 0.000040

int sync_blank_lines[] = {
    ( NTSC_SCANLINES - VIDEO_LINES - VERT_SYNC_SCANLINES ) / 2 ,
    ( PAL_SCANLINES - VIDEO_LINES - VERT_SYNC_SCANLINES ) / 2 ,
};

// ---------- VGA timings ----------
// VGA timing constants
#define F_PORCH     16
#define H_ACTIVE    (VIDEO_PIX_PER_LINE * 2) + F_PORCH - 1  // (active + frontporch - 1) - one cycle delay for mov
#define V_ACTIVE_400    400 - 1                             // (active - 1)
#define V_ACTIVE_480    480 - 1                             // (active - 1)
#define DAT_ACTIVE  VIDEO_PIX_PER_LINE - 1                  // horizontal active) - 1

#define VGA_DIV 5                                           // This gives 25MHz with a base clock of 125MHz

static uint16_t *video_mem_start;

void video_set_mem_start( uint16_t mem_start )
{
    video_mem_start = &mem_map[mem_start];
}

uint16_t video_get_mem_start( void )
{
    return (uint16_t) ( video_mem_start - mem_map );
}

static void video_gpio_pins( PIO pio )
{
    pio_gpio_init( pio, VSYNC );
    pio_gpio_init( pio, HSYNC );
    pio_gpio_init( pio, VIDEO );
    gpio_set_outover( VIDEO, GPIO_OVERRIDE_INVERT );
}

static int video_create_cvsync_sm( PIO pio )
{
    int cvsync_sm       = pio_claim_unused_sm( pio, true );                             // Claim a free state machine for video sync on PIO 1
    uint cvsync_offset  = pio_add_program( pio, &cvsync_program );                      // Instruction memory offset for the SM
    float sync_clockdiv = clock_get_hz( clk_sys ) * SYNC_INTERVAL;

    pio_sm_config cvsync_config = cvsync_program_get_default_config( cvsync_offset );   // Get default config for the pal video sync SM

    sm_config_set_sideset_pins( &cvsync_config, HSYNC );                                // Pin set for side instructions
    sm_config_set_clkdiv( &cvsync_config, sync_clockdiv );                              // Set the clock speed

    pio_sm_set_consecutive_pindirs( pio, cvsync_sm, HSYNC, 1, true );                   // Set HSYNC pin as output

    pio_sm_init( pio, cvsync_sm, cvsync_offset, &cvsync_config );

    pio_sm_put( pio, cvsync_sm, sync_blank_lines[config.video.system] - 1 );            // Tell the state machine the number of blank scanlines between vsync pulse
    pio_sm_put( pio, cvsync_sm, VIDEO_LINES - 1 );                                      // Tell the state machine the number of video lines (minus 1)

    return cvsync_sm;
}

static int video_create_cvdata_sm( PIO pio )
{
    int cvdata_sm       = pio_claim_unused_sm( pio, true );                             // Claim a free state machine for video data on PIO 1
    uint cvdata_offset  = pio_add_program( pio, &cvdata_program );                      // Instruction memory offset for the SM
    // Run the data clock 32x faster than needed to reduce horizontal jitter due to synchronisation between SMs
    float data_clockdiv = ( clock_get_hz( clk_sys ) / (VIDEO_PIX_PER_LINE / DATA_INTERVAL)) / CLOCKS_PER_BIT;

    pio_sm_config cvdata_config = cvdata_program_get_default_config( cvdata_offset );   // Get default config for the video data SM

    sm_config_set_out_pins(  &cvdata_config, VIDEO, 1 );                                // Pin set for OUT instructions.
    sm_config_set_set_pins(  &cvdata_config, VIDEO, 1 );                                // Pin set for SET instructions.
    sm_config_set_clkdiv( &cvdata_config, data_clockdiv );                              // Set the clock speed
    sm_config_set_out_shift( &cvdata_config, false, true, 8 );                          // Shift left DATA into OSR, autopush
    sm_config_set_fifo_join( &cvdata_config, PIO_FIFO_JOIN_TX );                        // Join FiFos for TX
    pio_sm_set_consecutive_pindirs( pio, cvdata_sm, VIDEO, 1, true );                   // Set HSYNC pin as output

    pio_interrupt_clear( pio, DATA_IRQ );                                               // Ensure that data IRQ is cleared at start

    pio_sm_init( pio, cvdata_sm, cvdata_offset, &cvdata_config );

    pio_sm_put( pio, cvdata_sm, VIDEO_PIX_PER_LINE - 1 );                               // Tell the state machine the number of pixels per line (minus 1)

    return cvdata_sm;
}

static int video_create_vgahsync_sm( PIO pio )
{
    int vgahsync_sm      = pio_claim_unused_sm( pio, true );                            // Claim a free state machine for horizontal video sync on PIO 1
    uint vgahsync_offset = pio_add_program( pio, &vgahsync_program );                   // Instruction memory offset for the SM

    pio_sm_config vgahsync_config = vgahsync_program_get_default_config( vgahsync_offset ); // Get default config for the pal video sync SM

    sm_config_set_set_pins( &vgahsync_config, HSYNC, 1 );                               // Pin set for set instructions
    sm_config_set_clkdiv( &vgahsync_config, VGA_DIV );                                  // Set the clock speed to 25.175MHz

    pio_sm_set_consecutive_pindirs( pio, vgahsync_sm, HSYNC, 1, true );                 // Set HSYNC pin as output

    pio_sm_init( pio, vgahsync_sm, vgahsync_offset, &vgahsync_config );

    pio_sm_put(pio, vgahsync_sm, H_ACTIVE);

    return vgahsync_sm;
}
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

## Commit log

2024-03-08 First firmware version
    [Jumper-green.step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]
2024-03-11 Add pull-up resistor to OE
    [kim-1-programmable-memory-B_Cu.gbr, kim-1-programmable-memory-B_Mask.gbr, kim-1-programmable-memory-B_Paste.gbr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]
2024-03-16 Add pin base definitions
2024-03-16 Complete rewrite using PIO and DMA
2024-03-18 Show value on power symbol for U7
    [kim-1-programmable-memory.kicad_sch]
2024-03-20 Disable DMA interrupts
2024-03-21 Print proper name
2024-03-22 New board design usign the RAMRW line
    [kim-1-programmable-memory-B_Cu.gbr, kim-1-programmable-memory-B_Mask.gbr, kim-1-programmable-memory-B_Paste.gbr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]
2024-04-18 New board design
    [CUI_DEVICES_RCJ-014.step, Micro_SD_Card_and_Holder.stp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]
2024-04-22 Add LCSC parts and correct video tracks impedance
    [kim-1-programmable-memory.kicad_pcb, kim-1-programmable-memory.kicad_sch]
2024-04-23 Minor silkscreen changes, track width corrections, open hole for Pico antenna
    [kim-1-programmable-memory-B_Cu.gbr, kim-1-programmable-memory-B_Mask.gbr, kim-1-programmable-memory-B_Paste.gbr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]
2024-05-08 New design: bus multiplexing and video and sd card support
    [kim-1-programmable-memory-B_Cu.gbr, kim-1-programmable-memory-B_Mask.gbr, kim-1-programmable-memory-B_Paste.gbr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]
2024-05-18 Switch networking code to the PicoWi library
2024-05-23 Print correct offset when writing
2024-05-24 Add warning about the interrupt vectors
2024-05-24 Add a picture of the prototype
2024-05-25 Add FatFS driver as a submodule
2024-05-25 Switch license to GPL V 3 to make it compatible with the Apache 2.0
2024-06-05 Removed submodule no-OS-FatFS-SD-SDIO-SPI-RPi-Pico
2024-06-10 Preliminary version of the K-1013 emulator
    [mkfs.xlsx]
2024-06-16 Fix dma configuration
2024-06-20 Fix calculation of fdc DMA address
2024-06-20 Option to switch debug completely off
2024-09-16 Silly silkscreen mistake
    [kim-1-programmable-memory-B_Cu.gbr, kim-1-programmable-memory-B_Mask.gbr, kim-1-programmable-memory-B_Paste.gbr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]
2025-01-28 Use interrupts for the extended commands to avoid some race conditions
2025-01-28 Check for valid drive / drive mounted
2025-02-19 (Hopefully) better status and interrupt management
2025-06-07 Report proper track 0 in sense drive commamd
2025-06-10 Fix 2 heads support
    [upd765.h]
2025-07-14 PAL-2 version
    [CUI_DEVICES_RCJ-014.step, Jumper-green.step, Micro_SD_Card_and_Holder.stp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]
2025-07-20 Read default mounts from the mount.cfg file
2025-07-20 Add saving current mounts to mount.cfg
2025-07-30 Add 'save mounts' option to the config command
2025-07-30 Add the mount command
2025-07-30 imd_mount_defaults() was incorrectly mounting images RO
2025-08-28 Add KIM-1 adapter for the PAL-2 version
    [pal-2-kim-adapter-B_Cu.gbr, pal-2-kim-adapter-B_Mask.gbr, pal-2-kim-adapter-B_Paste.gbr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]
2025-08-30 Add BOM and component placement files by Luciano Veronese
    [bom.csv, positions.csv]
2025-11-13 Reduce jitter
2025-11-13 Add 640x480@60Hz VGA mode
2026-02-07 Upgrade to latest pico-sdk
2026-02-07 Make clang happy with curly braces in case statements
2026-06-28 Add forced DECEN for higher addresses to the PAL-2-KIM adapter (#9)
    [pal-2-kim-adapter-B_Cu.gbr, pal-2-kim-adapter-B_Mask.gbr, pal-2-kim-adapter-B_Paste.gbr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]

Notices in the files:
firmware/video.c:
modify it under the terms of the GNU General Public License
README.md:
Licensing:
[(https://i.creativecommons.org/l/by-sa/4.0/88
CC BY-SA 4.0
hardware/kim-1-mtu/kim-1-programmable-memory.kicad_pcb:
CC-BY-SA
